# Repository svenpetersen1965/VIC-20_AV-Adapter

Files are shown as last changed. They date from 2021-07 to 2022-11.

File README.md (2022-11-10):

# VIC-20 A/V-Adapter
An Adapter for connecting the Commodore VIC-20 to video equipment with off the shelve A/V-cables.

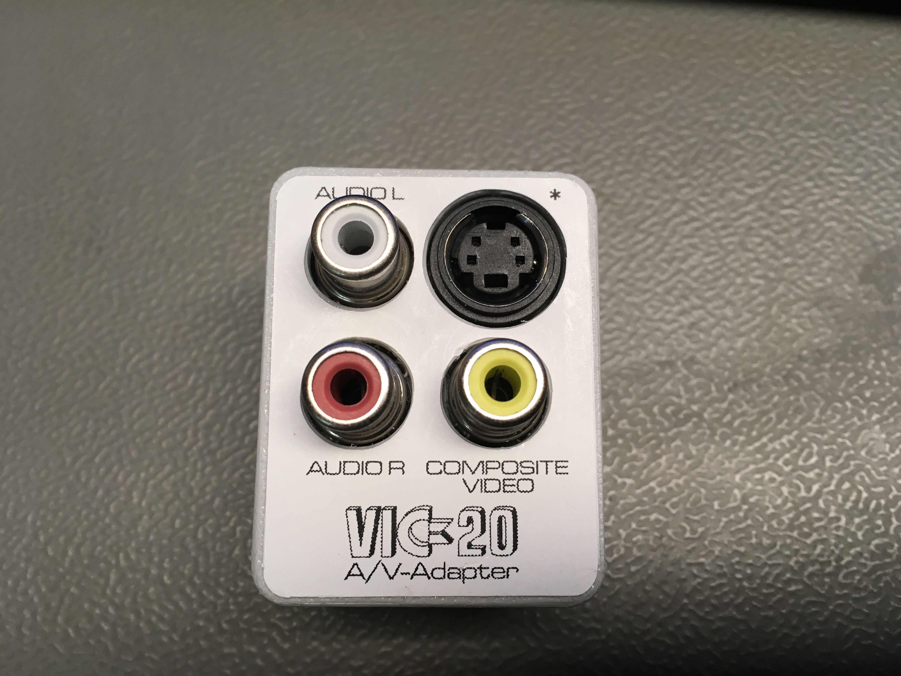
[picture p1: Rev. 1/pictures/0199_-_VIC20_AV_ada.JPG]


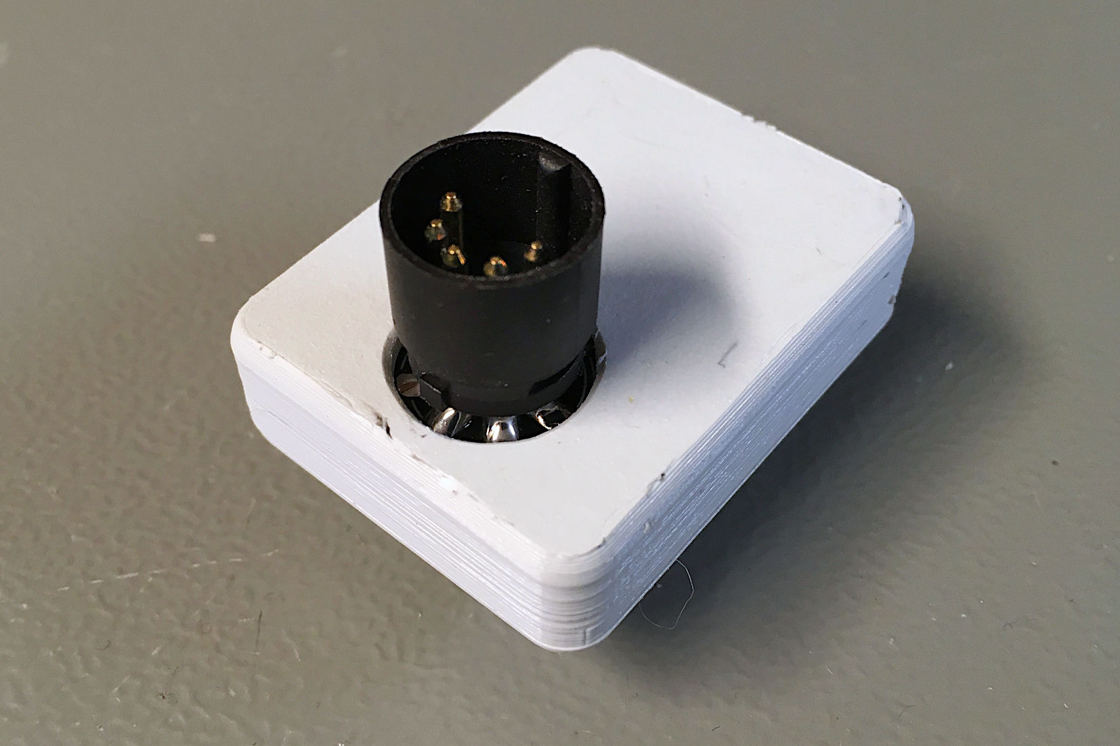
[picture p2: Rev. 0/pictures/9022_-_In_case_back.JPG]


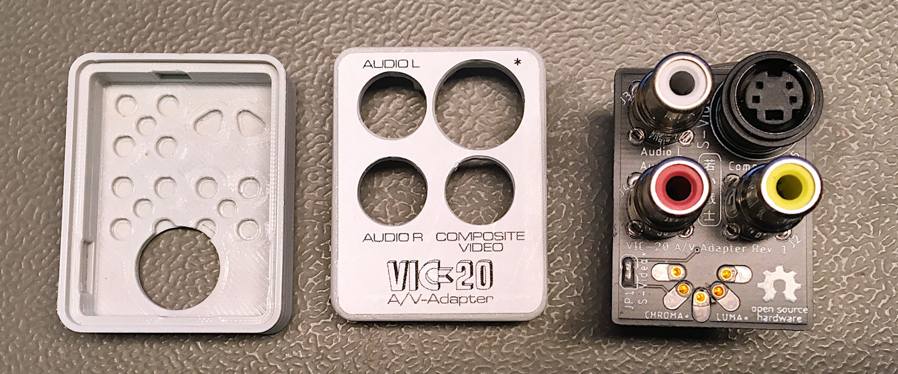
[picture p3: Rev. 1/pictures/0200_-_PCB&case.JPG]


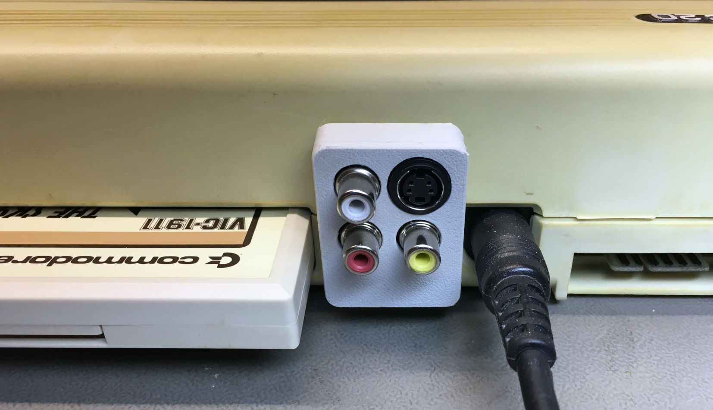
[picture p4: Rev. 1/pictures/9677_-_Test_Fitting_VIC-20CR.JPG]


A 3D printed case and a case label are provided in this repository.

The A/V-adapter was tested with
* the Commodore VIC-20
* the Commodore C16
* the Commodore C64
* the Atari 800XL

It is not suitable for the Commodore C128
# BOM Value
The BOM value of Rev. 1, without the 3D printed case and label is 9.50€ (01.11.2021, values obtained from Reichelt.de). The Lumberg connectors are more expensive from other suppliers.

# Rev. 2
The Lumberg BTOR1 RCA jacks were obsolete and replaced with CUI Inc. RCJ-02*. This also requires a different bottom shell of the 3D-printed case. There are Keystome RCA jacks, that fit the same footprint (they are more expensive). See the BOM Rev. 2

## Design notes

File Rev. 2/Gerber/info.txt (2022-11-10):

      
       Board: VIC-20_AV-Adaptor
       Rev.:  2
  
       Files:
       ======
  
       All Gerber files are generated in extended gerber format (RS274X)
       *.TOP        : Film top copper
       *.BOT        :  -"- bottom copper
       *.STC        :  -"- top soldermask 
       *.STS        :  -"- bottom soldermask
       *.PLC        :  -"- silk screen top
       *.PLS        :  -"- silk screen bottom
       *.DK         : Drills plated Through (Excellon)
       *.NDK        : Drills not plated Through (Excellon)
       *.OUT        : Board outline

       Board Size:
       ===========
       Length     :   39.0 mm
       Width      :   29.0 mm
       Thickness  :   1.6 mm
       Material   :   FR 4
       Copper     :   35 um
       Surface    :   HASL
       
       Remarks:
       ========
       Width >= 8mil
       Distance >= 6mil
       Drill >= 0.6mm

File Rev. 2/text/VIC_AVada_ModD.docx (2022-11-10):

-Commodore VIC-20 A/V-Adapter Rev. 2

Module Description

# Introduction

The VIC-20 A/V-Adapter serves as a breakout module for the 5-pin A/V jack, which allows using off the shelve cables of desired length and quality for connecting the VIC-20 to video/audio equipment.

The adapter is passive, it does not improve the video quality, but it helps to prevent video degradation. The S-Video jack works with VIC-20s, that are modified only. (S-Video mod like here: http://sleepingelephant.com/denial/wiki/index.php?title=S-Video_output or here: http://tech.guitarsite.de/vicky20_smod.html). The adapter does not generate S-Video!

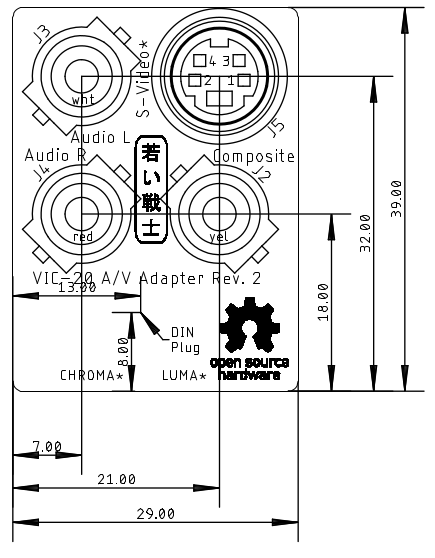
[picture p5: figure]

Figure 1: Dimensions of the PCB

The two audio jacks (Audio L and Audio R) are connected to the same signal, the (mono) Audio Out of the VIC-20.

A 3D printable case can be found in the project folder as well as a label for this case. The case for Rev. 0 and Rev. 1 is different from the case for Rev. 2.

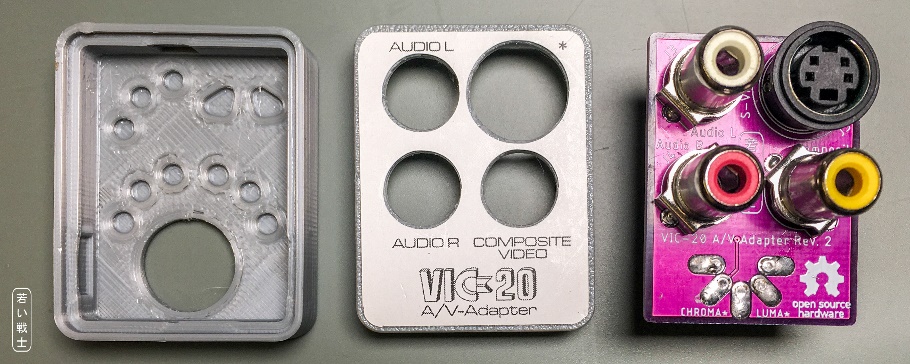
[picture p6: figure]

Figure 2: 3D printed case and assembled PCB

# Connectors

## A/V-Plug – J1

The A/V-Plug for the VIC-20 is the inner part of a Lumberg SV 50 DIN-Plug (180°).

Pin | Signal
1 | n.c.
2 | GND
3 | Audio Out (mono)
4 | Composite Video/LUMA*
5 | CHROMA*

* After S-Video mod.

## RCA-Jacks – J2, J3, J4

Connector | Signal
J2 | Composite Video
J3 | Audio Out L (mono!)
J4 | Audio Out R (mono!)

# The DIN-Plug

The DIN-Plug is an essential part of this development. It is the inner part of a Lumberg SV 50 connector, which is not cheap, but it is definitely worth the money, since the flange is taking the forces introduced by the weight of the adapter and the cables. This way, the set-up is not hanging from the contacts, which might even damage those. Do not use a cheap connector without a flange, here.

# Assembly

First, the DIN connector has to be soldered. The pins should be aligned flush to the top side of the PCB. This can be accomplished by putting the PCB top down on a heat resistant, flat surface. Then solder one pin from the top (the solder pads are shaped in a way, that allows doing so), check, if it is really flush and the connector is perpendicular to the board, then solder the remaining pins.

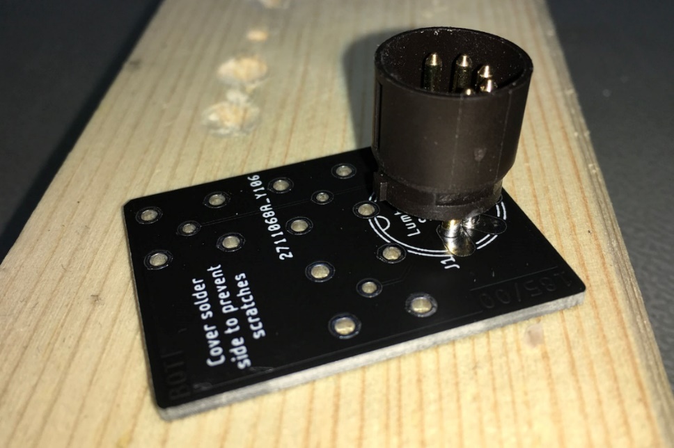
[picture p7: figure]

Figure 3: Aligning the DIN-Connector (PCB Rev. 0)

Now, place and solder the mini-DIN and finally the RCA jacks. They should be well aligned, too. The ground pins might require more energy to be soldered, so the use of a thick solder tip is recommended and may be even a higher temperature (450°C). After soldering, the pins should be trimmed (shorter than 1.5mm), so they fit into the 3D-Printed case. If you do not use a case, cover the pins with something like duct tape or small drops of hot glue to prevent scratching the case of your VIC-20.

# Compatibility

The adapter also fits the C64 (in case S-Video is not required), especially the first C64 model with the 5-pin A/V-jack (this does not have the S-Video outputs). The same is for the C16. The VIC-20 A/V-Adapter does not work for the C128, since it blocks the serial bus. The adapter was also successfully tested with an Atari 800XL (composite).

# Annotation

The said S-Video mod exposes the CHROMA pin of the VIC chip almost directly to the connector. This might get critical, if the VIC-20or any of the video devices is switched on/connected to a PSU. I would definitely recommend a careful way of connecting the cables and devices.

# Revision History

## Rev. 0

- Fully functional prototype

## Rev. 0 → Rev. 1

- S-Video jack for modified VIC-20 added.

## Rev. 1 → Rev. 2

- Replaced the obsolescent Lumberg BTOR1 RCA-jacks with CUI Inc. RCJ-02x type. There are alternative Keystone parts, that fit the same footprint (see BOM v2).
- A new 3D-pinted case is required (bottom shell)

VIC_AVada_ModD.docx 10.11.2022 16:17 Drafted by Sven Petersen Page 2 of 2 Doc.-No.: 185-6-01-02

VIC_AVada_ModD.docx 10.11.2022 16:17 Drafted by Sven Petersen Page 1 of 1 Doc.-No.: 000-6-00-00

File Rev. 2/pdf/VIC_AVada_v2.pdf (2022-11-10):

# Project Documentation

## Commodore VIC-20 A/V-Adapter

## Project number: 185

## Revision: 2

## Date: 10.11.2022

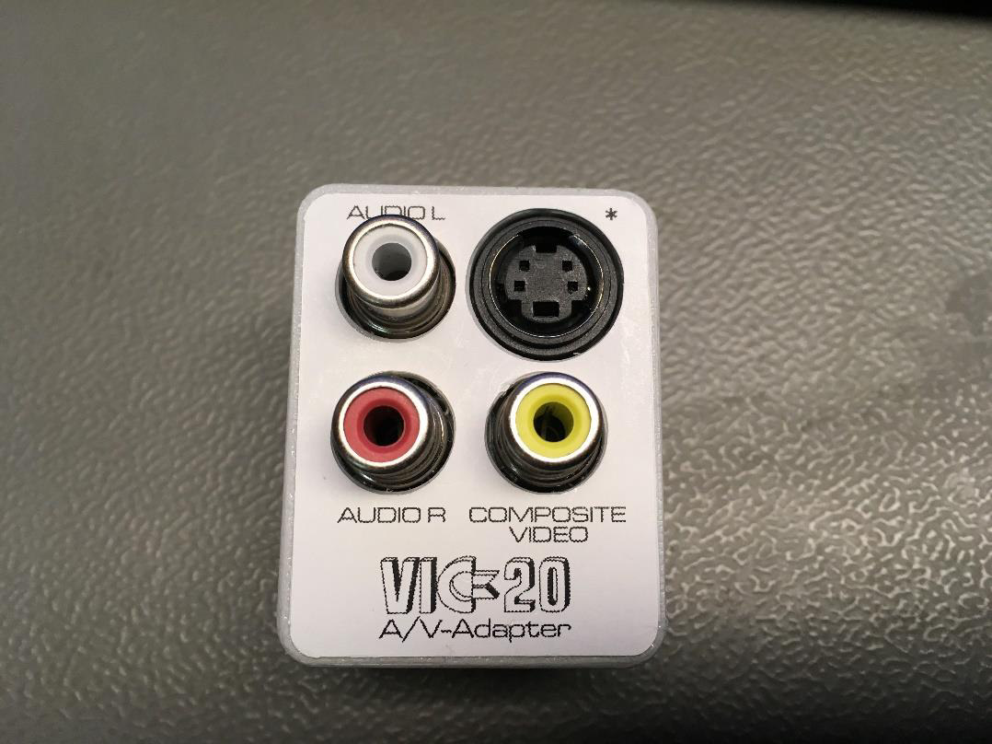
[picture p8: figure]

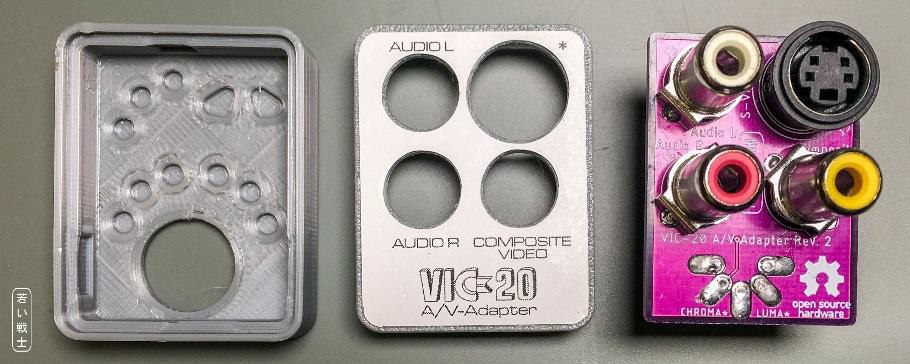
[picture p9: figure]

VIC_AVada_ModD.docx | | 10.11.2022 16:17
Drafted by Sven Petersen | Page 1 of 3 | Doc.-No.: 185-6-01-02

### -Commodore VIC-20 A/V-Adapter Rev. 2

### Module Description

## Introduction

The VIC-20 A/V-Adapter serves as a breakout module for the 5-pin A/V jack, which allows using off the shelve cables of desired length and quality for connecting the VIC-20 to video/audio equipment.

The adapter is passive, it does not improve the video quality, but it helps to prevent video degradation. The S-Video jack works with VIC-20s, that are modified only. (S-Video mod like
here: | http://sleepingelephant.com/denial/wiki/index.php?title=S-Video_output | or | here:
http://tech.guitarsite.de/vicky20_smod.html). The adapter does not generate S-Video!

Figure 1: Dimensions of the PCB

The two audio jacks (Audio L and Audio R) are connected to the same signal, the (mono) Audio Out of the VIC-20.

A 3D printable case can be found in the project folder as well as a label for this case. The case for Rev. 0 and Rev. 1 is different from the case for Rev. 2.

Figure 2: 3D printed case and assembled PCB

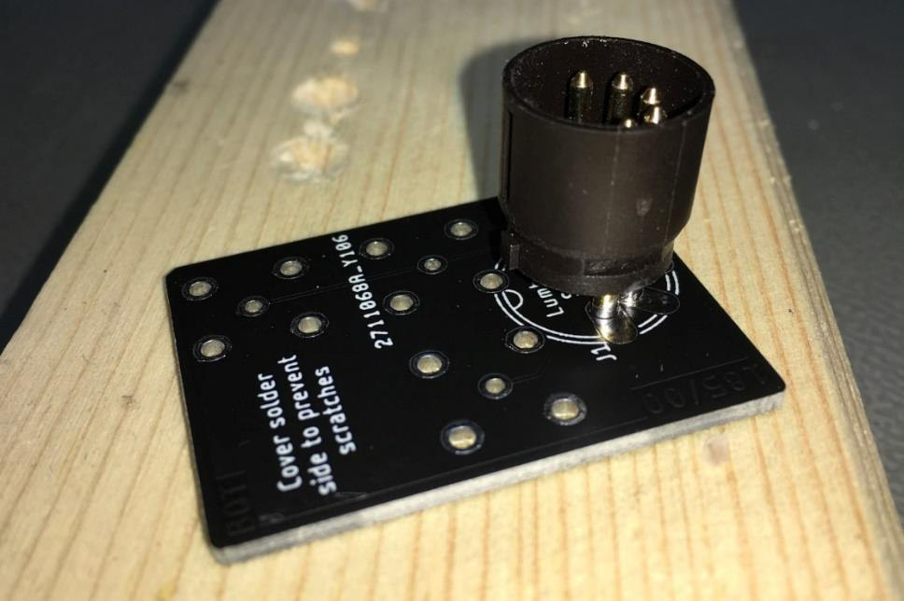
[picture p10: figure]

VIC_AVada_ModD.docx | | 10.11.2022 16:17
Drafted by Sven Petersen | Page 2 of 3 | Doc.-No.: 185-6-01-02

## Connectors

### A/V-Plug – J1

The A/V-Plug for the VIC-20 is the inner part of a Lumberg SV 50 DIN-Plug (180°).

Pin Signal
1 n.c.
2 GND
3 Audio Out (mono)
4 Composite Video/LUMA*
5 CHROMA*

* After S-Video mod.

### RCA-Jacks – J2, J3, J4

Connector Signal
J2 | Composite Video
J3 | Audio Out L (mono!)
J4 | Audio Out R (mono!)

## The DIN-Plug

The DIN-Plug is an essential part of this development. It is the inner part of a Lumberg SV 50 connector, which is not cheap, but it is definitely worth the money, since the flange is taking the forces introduced by the weight of the adapter and the cables. This way, the set-up is not hanging from the contacts, which might even damage those. Do not use a cheap connector without a flange, here.

## Assembly

First, the DIN connector has to be soldered. The pins should be aligned flush to the top side of the PCB. This can be accomplished by putting the PCB top down on a heat resistant, flat surface. Then solder one pin from the top (the solder pads are shaped in a way, that allows doing so), check, if it is really flush and the connector is perpendicular to the board, then solder the remaining pins.

Figure 3: Aligning the DIN-Connector (PCB Rev. 0)

VIC_AVada_ModD.docx | | 10.11.2022 16:17
Drafted by Sven Petersen | Page 3 of 3 | Doc.-No.: 185-6-01-02

Now, place and solder the mini-DIN and finally the RCA jacks. They should be well aligned, too. The ground pins might require more energy to be soldered, so the use of a thick solder tip is recommended and may be even a higher temperature (450°C). After soldering, the pins should be trimmed (shorter than 1.5mm), so they fit into the 3D-Printed case. If you do not use a case, cover the pins with something like duct tape or small drops of hot glue to prevent scratching the case of your VIC-20.

## Compatibility

The adapter also fits the C64 (in case S-Video is not required), especially the first C64 model with the 5-pin A/V-jack (this does not have the S-Video outputs). The same is for the C16. The VIC-20 A/V-Adapter does not work for the C128, since it blocks the serial bus. The adapter was also successfully tested with an Atari 800XL (composite).

## Annotation

The said S-Video mod exposes the CHROMA pin of the VIC chip almost directly to the connector. This might get critical, if the VIC-20or any of the video devices is switched on/connected to a PSU. I would definitely recommend a careful way of connecting the cables and devices.

## Revision History

### Rev. 0

- Fully functional prototype

### Rev. 0 → Rev. 1

- S-Video jack for modified VIC-20 added.

### Rev. 1 → Rev. 2

- Replaced the obsolescent Lumberg BTOR1 RCA-jacks with CUI Inc. RCJ-02x type. There are alternative Keystone parts, that fit the same footprint (see BOM v2).
- A new 3D-pinted case is required (bottom shell)

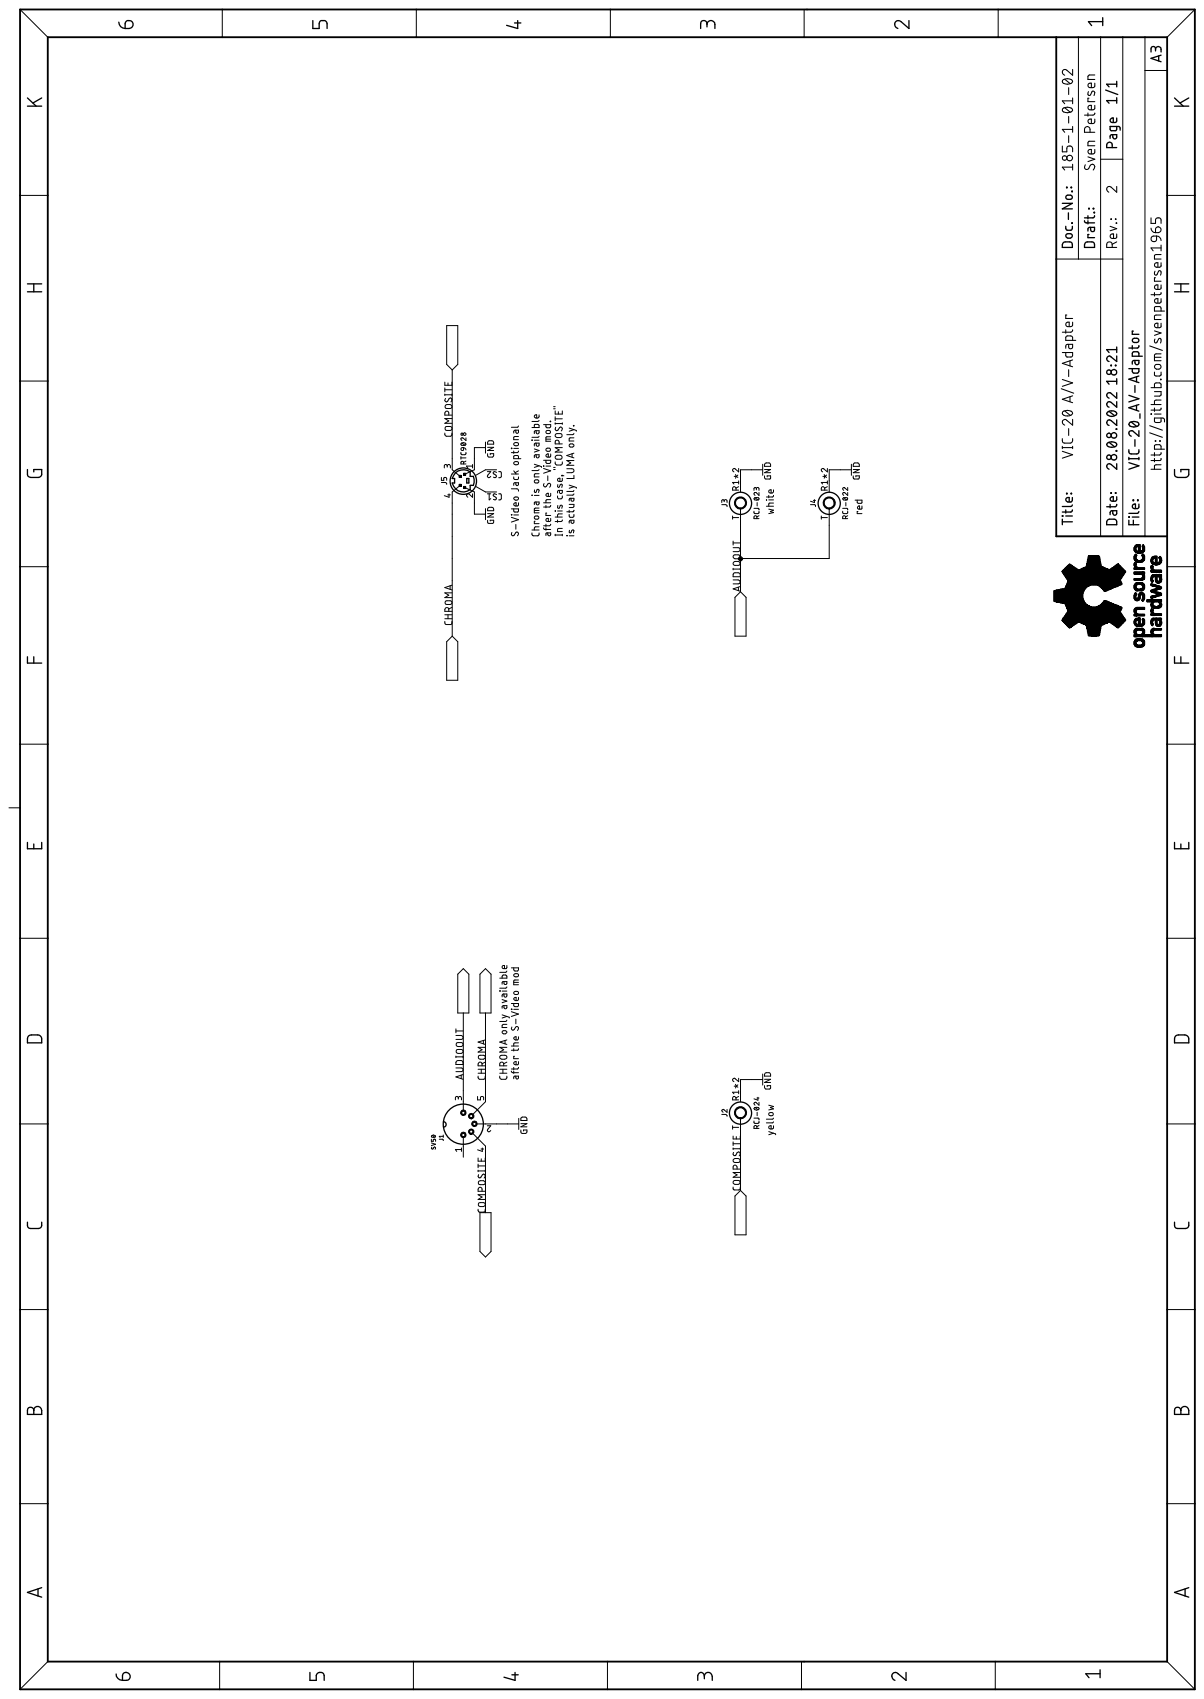
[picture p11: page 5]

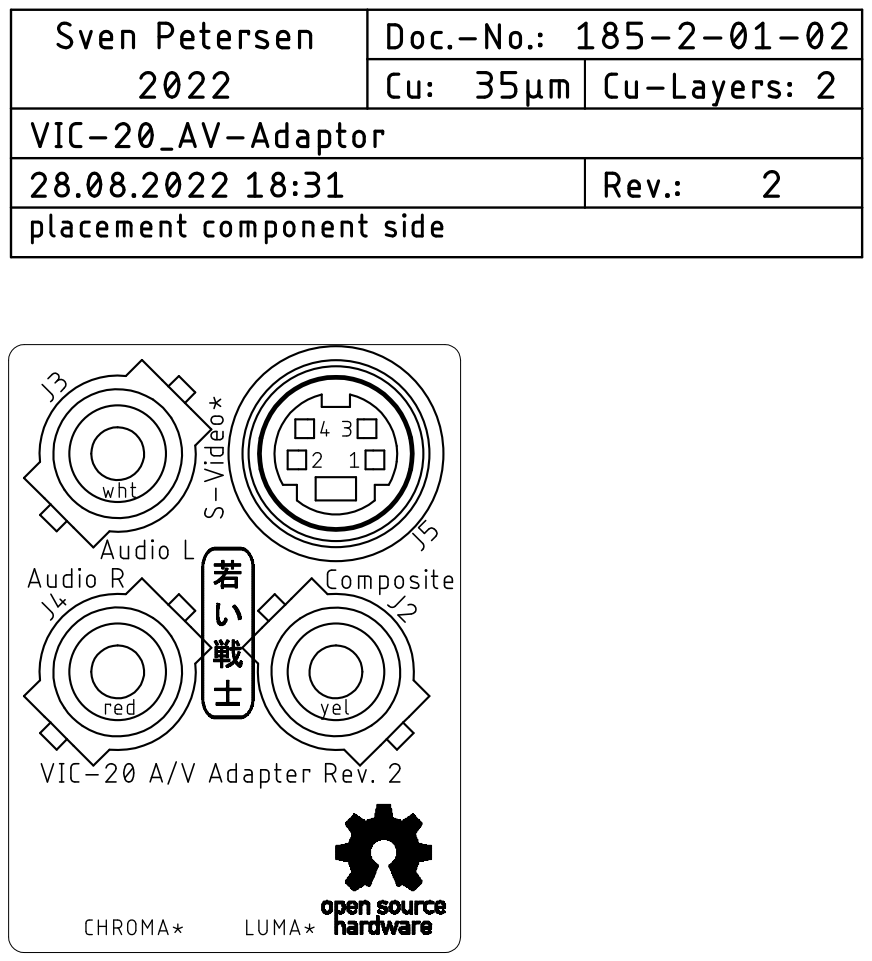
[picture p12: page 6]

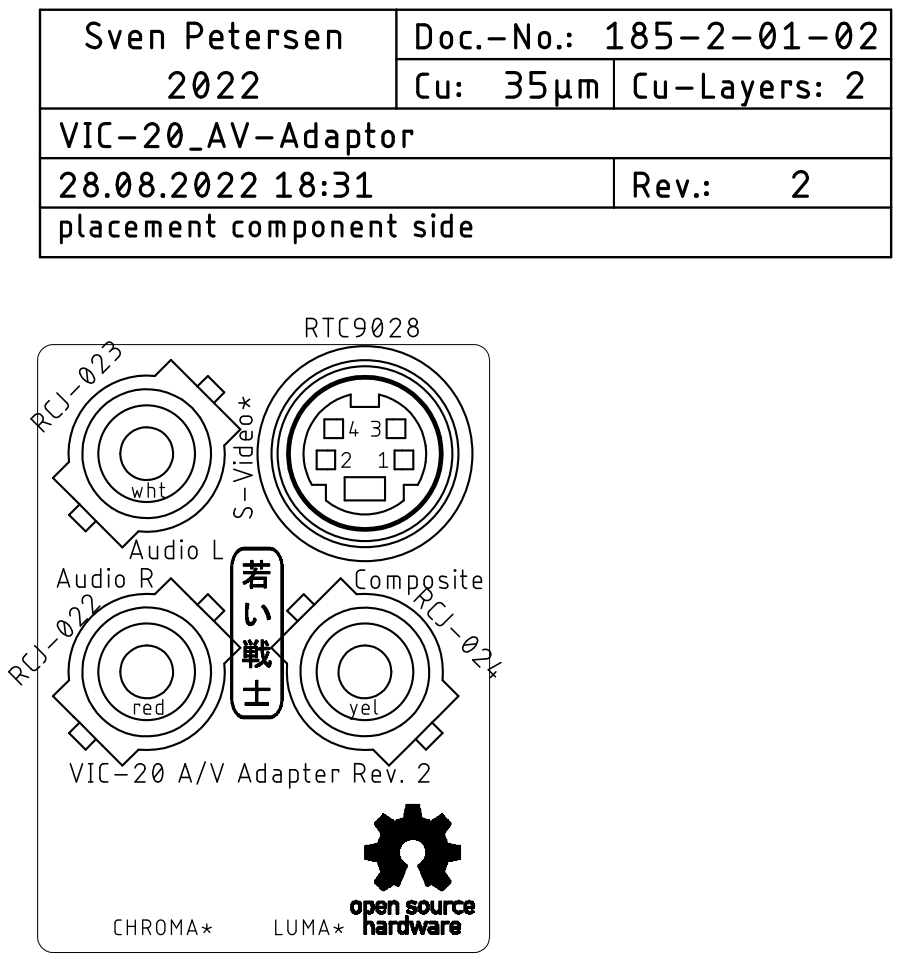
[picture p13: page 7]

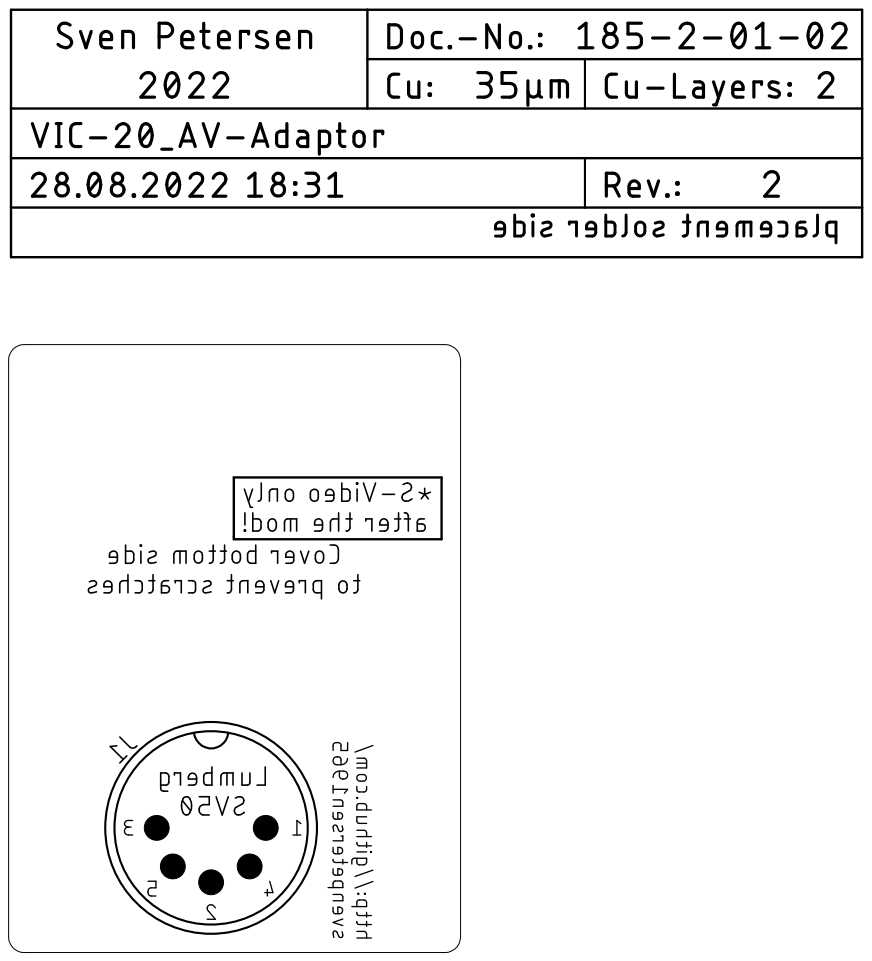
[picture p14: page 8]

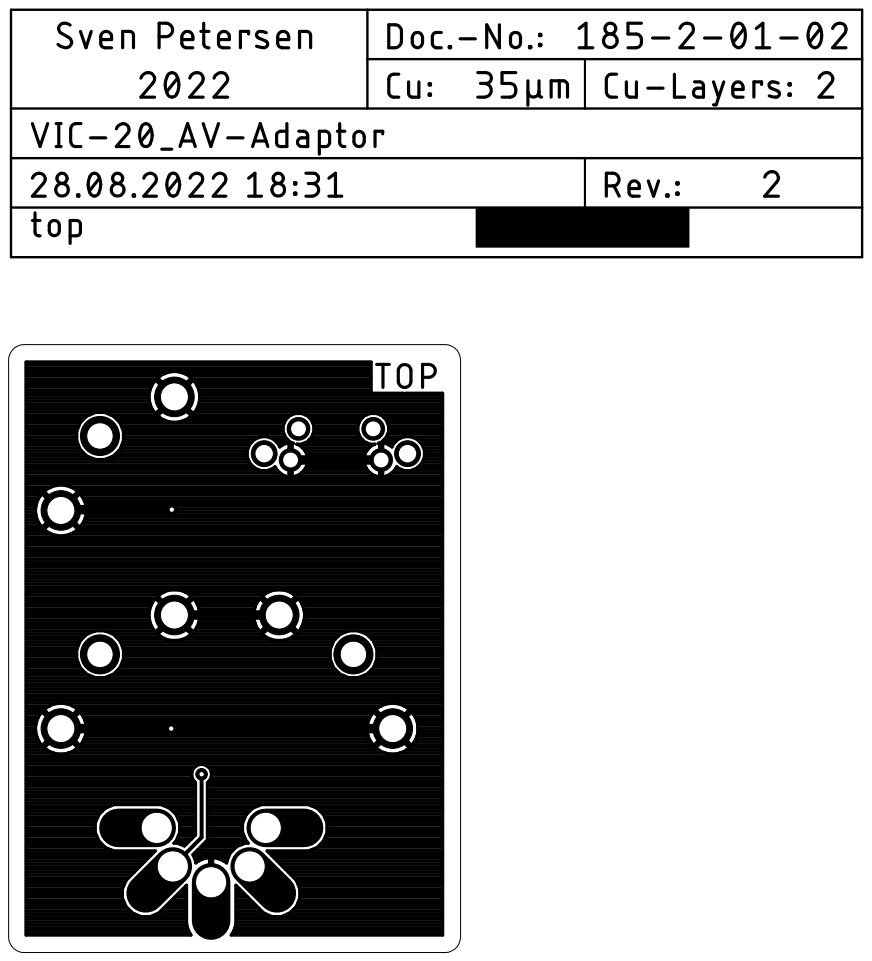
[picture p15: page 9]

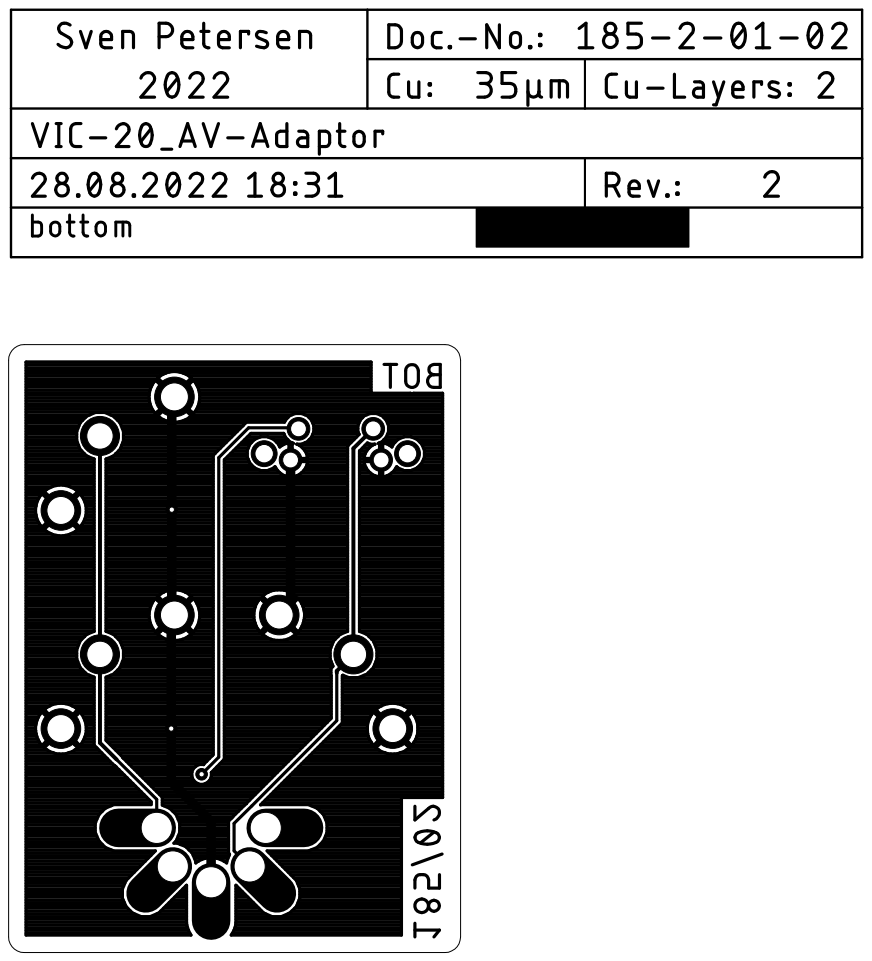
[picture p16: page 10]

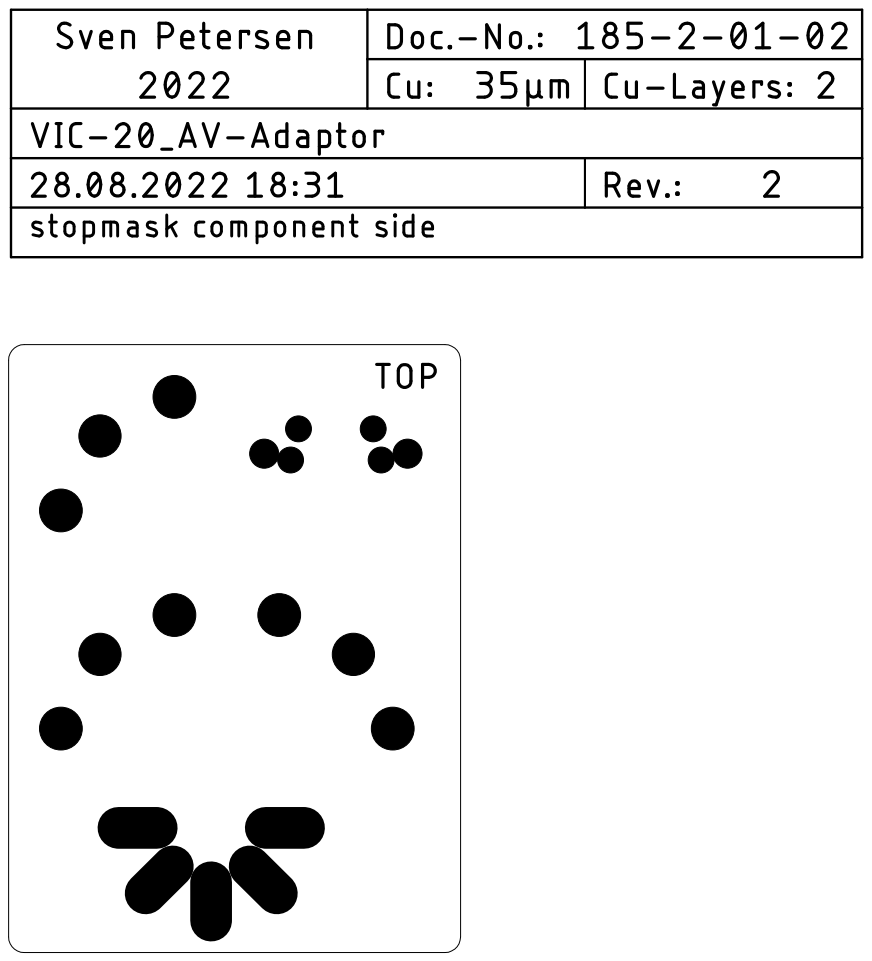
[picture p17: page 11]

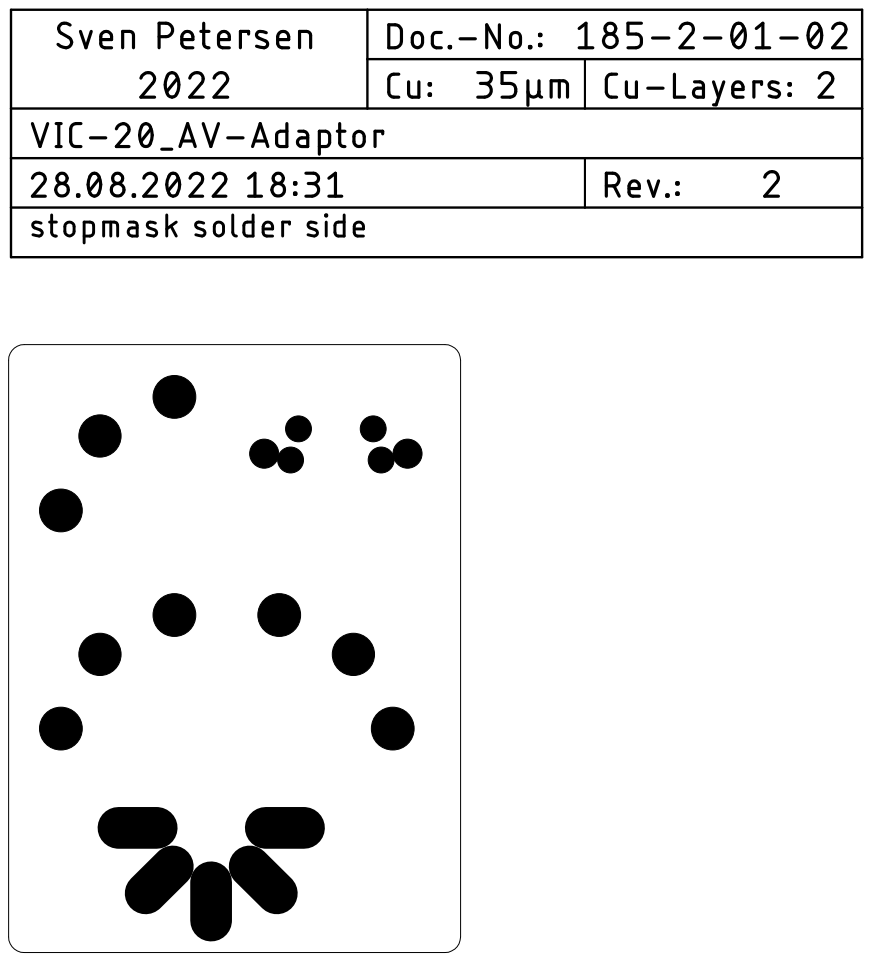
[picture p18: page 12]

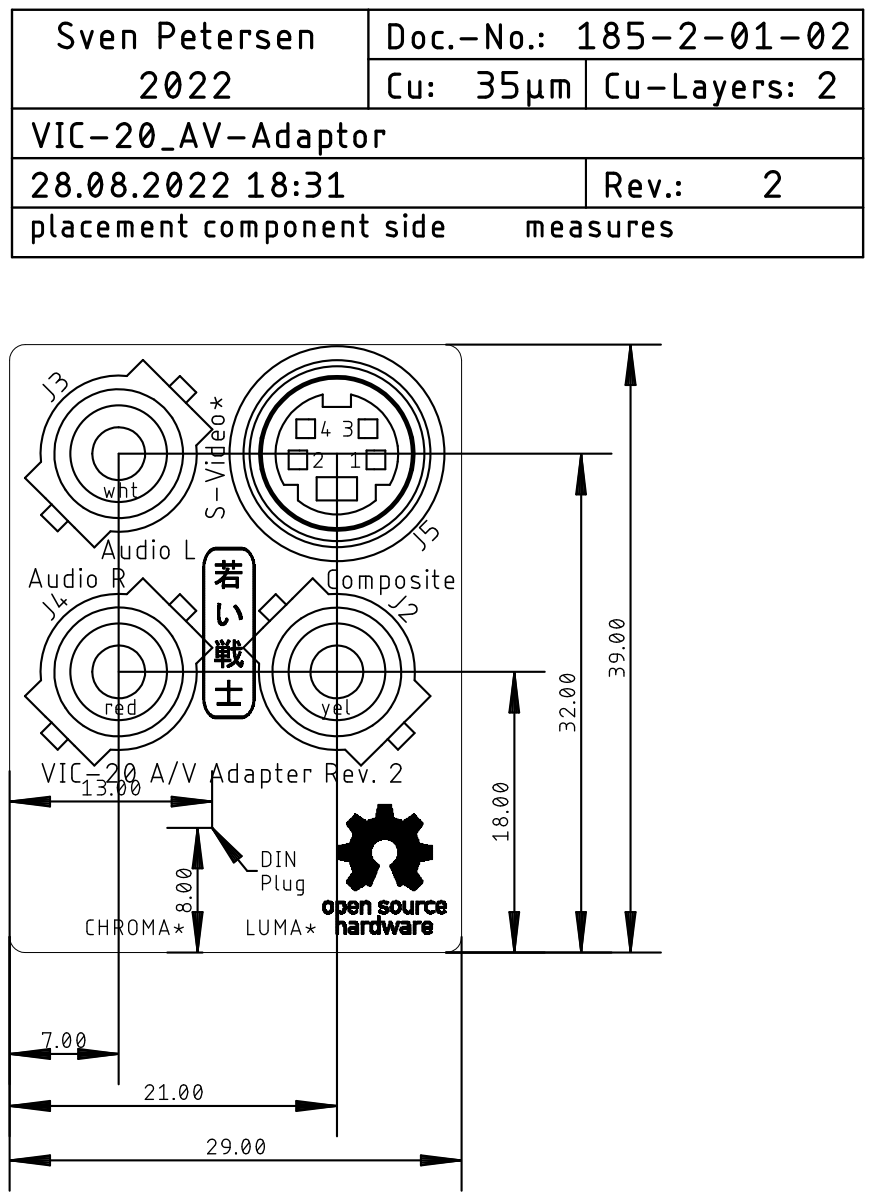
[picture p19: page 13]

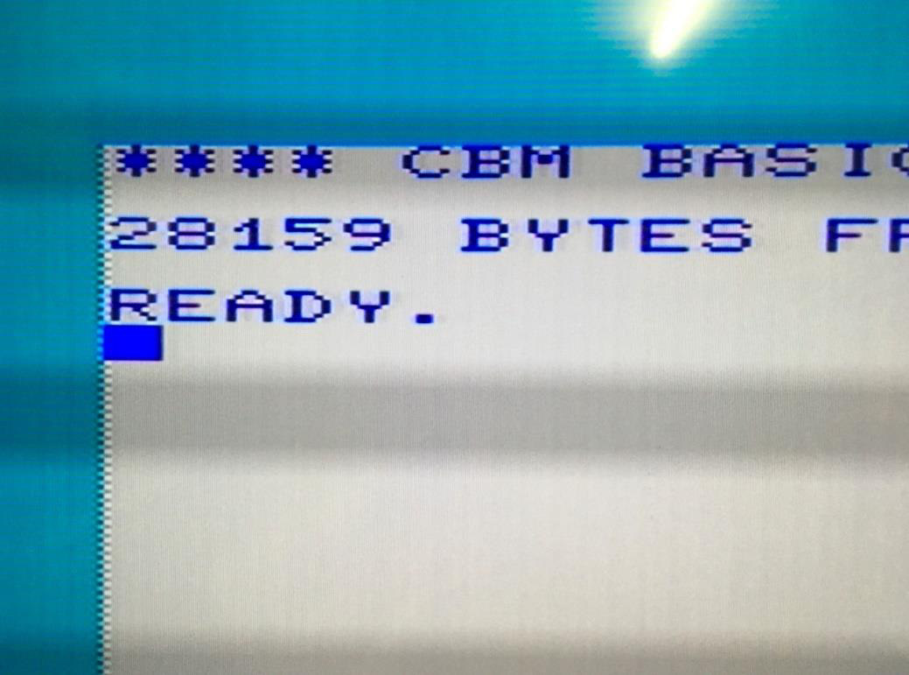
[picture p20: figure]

VIC_AVada_Test.docx | | 10.11.2022 16:18
Drafted by Sven Petersen | Page 1 of 7 | Doc.-No.: 185-6-02-02

### Commodore VIC-20 A/V-Adapter Rev. 2

### Test

## Test Setup

The tests were executed with a VIC-20 A/V-Adapter Rev. 1 and Rev. 2. These computers were used for testing:

1. A VickyTwenty (clone of the VIC-20CR) in a plexilaser.de case
2. A two-prong VIC-20 (ASSY No. 324003)
3. A VIC-20CR (ASSY No. ASSY250403)
4. C64 ASSY No. 250469

The VickyTwenty has the S-Video modification (sleepingelephant.com (http://sleepingelephant.com/denial/wiki/index.php?title=S-Video_output) or tech.guitarsite.de, (http://tech.guitarsite.de/vicky20_smod.html) respectively).

The retroTINK 2x (used with the HDMI capture device), the Framemeister (used with the TV) and a Samsung smart TV served as video equipment. A 1.5m RCA A/V cable connected the computer to the video equipment.

## Functional Test

The A/V adapter was connected to the computers and the video was displayed properly, the audio could be heard.

Figure 1: Boot screen of the VIC-20 CR (Hyper Expander RAM expansion installed)

The video quality was as good as it can get with the unmodified VIC-20. The video quality of ASSY No. 324003 is best, next is the Vicky Twenty.

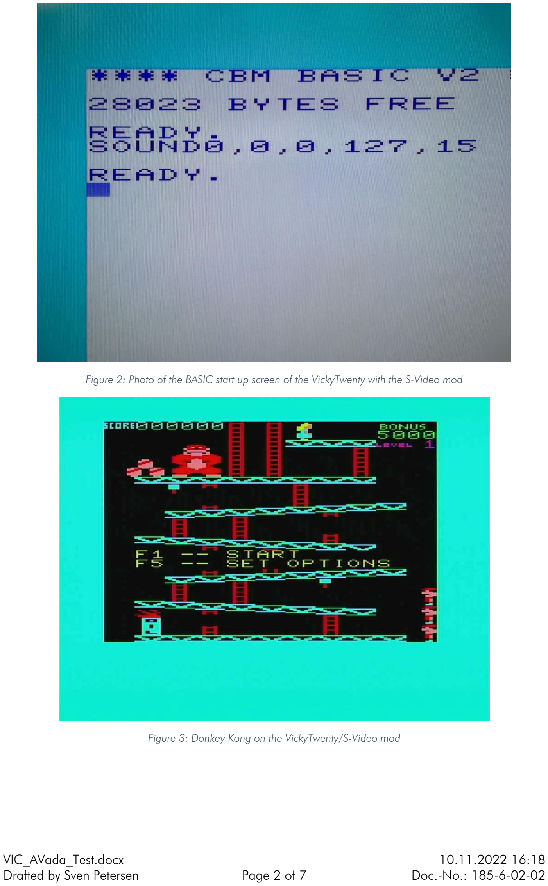
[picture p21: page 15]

VIC_AVada_Test.docx | | 10.11.2022 16:18
Drafted by Sven Petersen | Page 2 of 7 | Doc.-No.: 185-6-02-02

Figure 2: Photo of the BASIC start up screen of the VickyTwenty with the S-Video mod

Figure 3: Donkey Kong on the VickyTwenty/S-Video mod

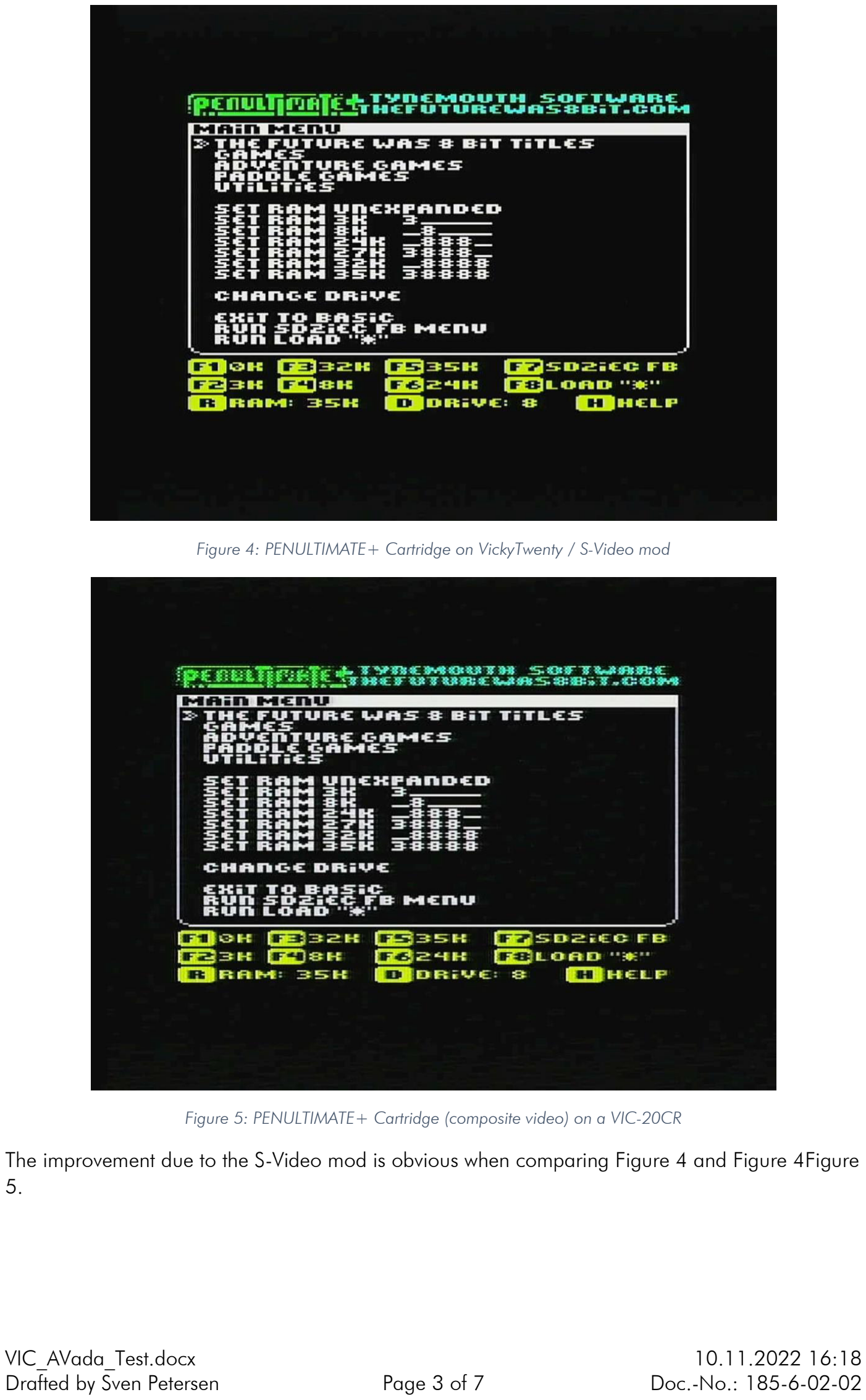
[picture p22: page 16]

VIC_AVada_Test.docx | | 10.11.2022 16:18
Drafted by Sven Petersen | Page 3 of 7 | Doc.-No.: 185-6-02-02

Figure 4: PENULTIMATE+ Cartridge on VickyTwenty / S-Video mod

Figure 5: PENULTIMATE+ Cartridge (composite video) on a VIC-20CR

The improvement due to the S-Video mod is obvious when comparing Figure 4 and Figure 4Figure 5.

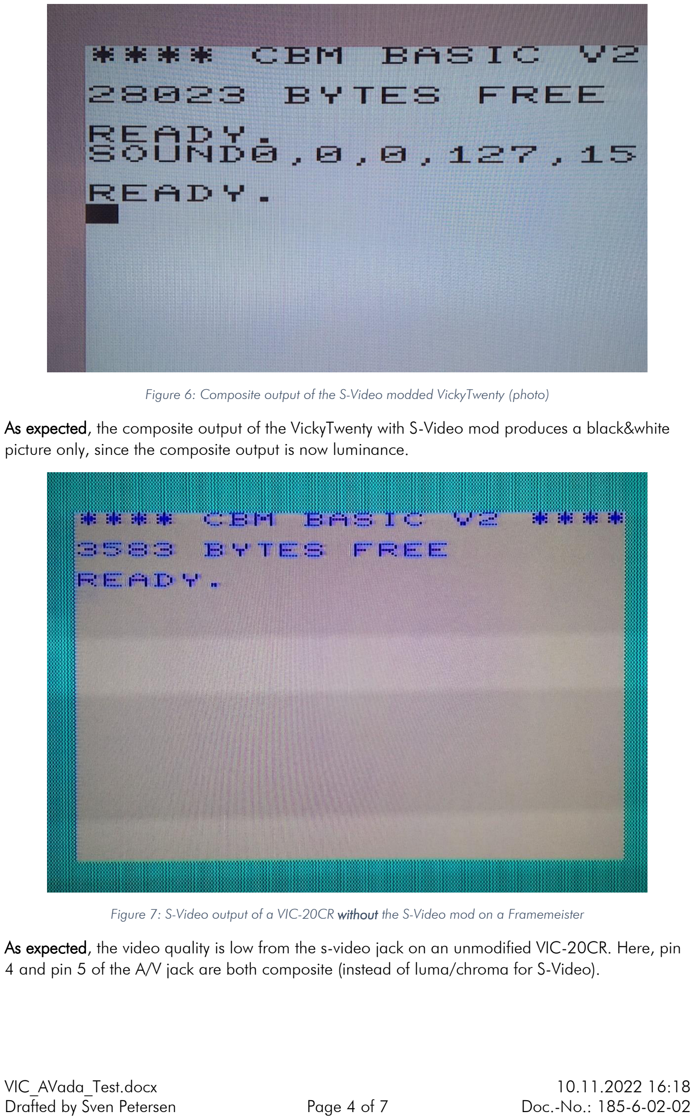
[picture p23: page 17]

VIC_AVada_Test.docx | | 10.11.2022 16:18
Drafted by Sven Petersen | Page 4 of 7 | Doc.-No.: 185-6-02-02

Figure 6: Composite output of the S-Video modded VickyTwenty (photo)

As expected, the composite output of the VickyTwenty with S-Video mod produces a black&white picture only, since the composite output is now luminance.

Figure 7: S-Video output of a VIC-20CR without the S-Video mod on a Framemeister

As expected, the video quality is low from the s-video jack on an unmodified VIC-20CR. Here, pin 4 and pin 5 of the A/V jack are both composite (instead of luma/chroma for S-Video).

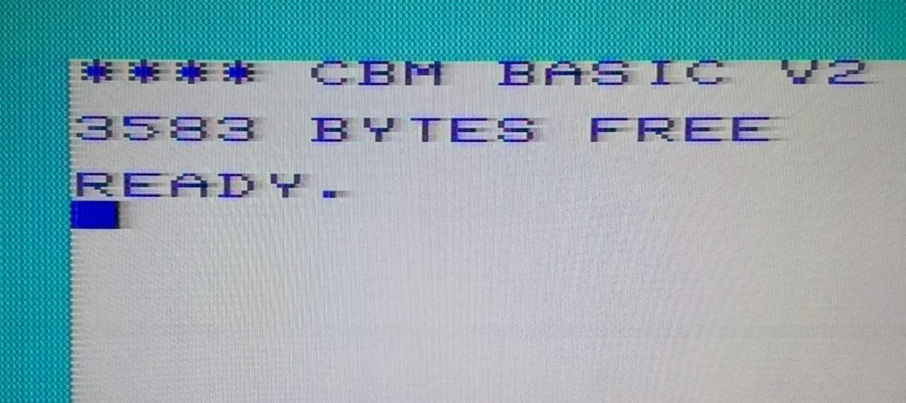
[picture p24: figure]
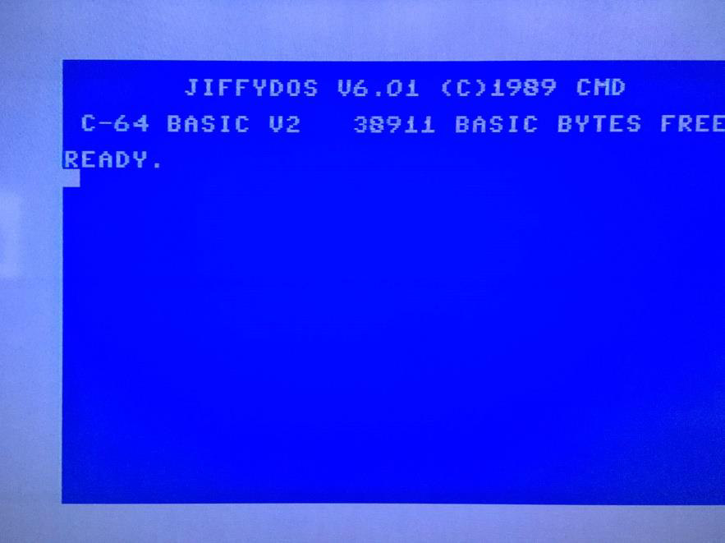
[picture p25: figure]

VIC_AVada_Test.docx | | 10.11.2022 16:18
Drafted by Sven Petersen | Page 5 of 7 | Doc.-No.: 185-6-02-02

Figure 8: S-Video output of the unmodified VIC-20 (2 prong)

As expected, the output is degraded. The 2-prong VIC-20 has a different video circuitry as the VIC-20CR. Pin 4 and pin 5 are not tied together, but pin 4 is a composite signal (Pin 5) after an L/C-
low pass filter. Thus, the different output “quality” of incorrectly connected VIC-20s.

Figure 9: Photo of the C64 boot screen (composite Video)

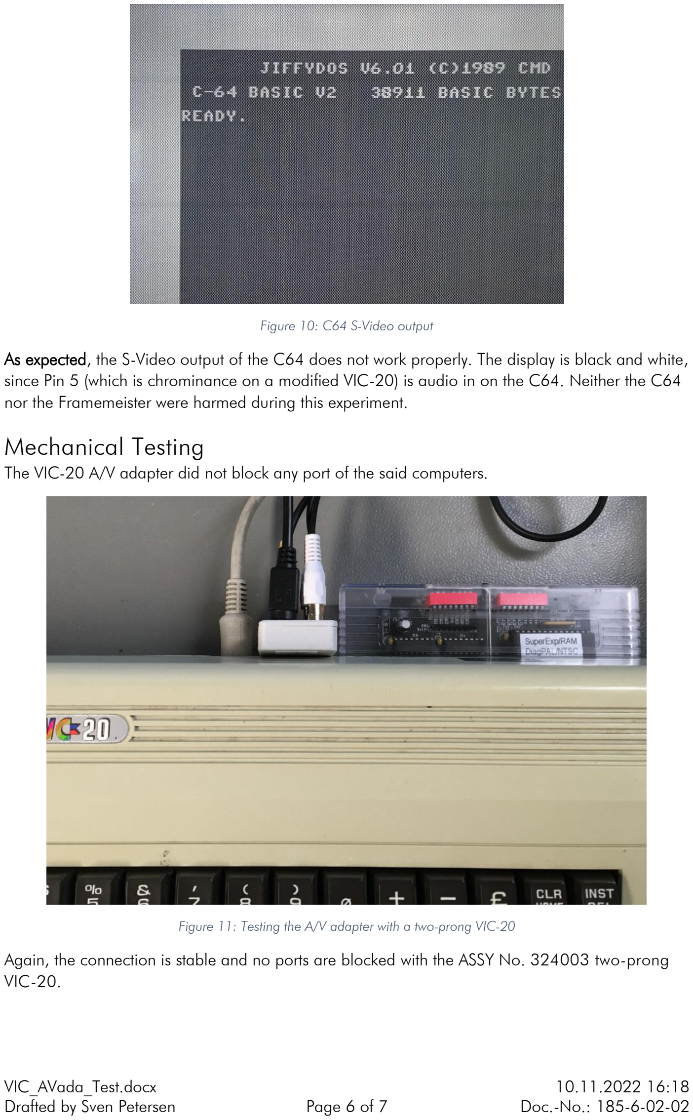
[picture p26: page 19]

VIC_AVada_Test.docx | | 10.11.2022 16:18
Drafted by Sven Petersen | Page 6 of 7 | Doc.-No.: 185-6-02-02

Figure 10: C64 S-Video output

As expected, the S-Video output of the C64 does not work properly. The display is black and white, since Pin 5 (which is chrominance on a modified VIC-20) is audio in on the C64. Neither the C64 nor the Framemeister were harmed during this experiment.

## Mechanical Testing

The VIC-20 A/V adapter did not block any port of the said computers.

Figure 11: Testing the A/V adapter with a two-prong VIC-20

Again, the connection is stable and no ports are blocked with the ASSY No. 324003 two-prong VIC-20.

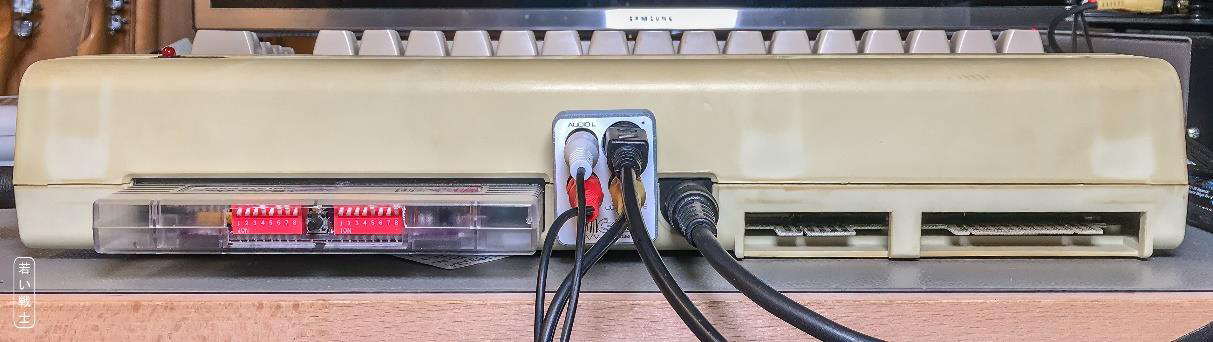
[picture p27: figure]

VIC_AVada_Test.docx | | 10.11.2022 16:18
Drafted by Sven Petersen | Page 7 of 7 | Doc.-No.: 185-6-02-02

Figure 12: Fitting of the A/V-Adapter with a VIC-20CR

## Conclusion

The VIC-20 A/V-Adapter works well with different equipment. The video quality depends very much on the used video equipment. The video adapter will not improve the picture of the computers, since it is passive only, but since it allows to use good, off the shelve cables, it is superior to most handmade custom cables.

Connecting S-Video to not modified VIC-20s does not harm the video equipment or the computer, but the quality is degraded. The same applies to the C64, which has its dedicated S-Video pins, that are not connected to the S-Video jack of the VIC-20 A/V-Adapter. The composite out of the C64 is displayed properly through the VIC-20 A/V-Adapter.

The VIC-20 A/V-Adaptor Rev. 2 is fully functional.

Pos. Qty Value Footprint Ref.-No. Comment

1 1 185-2-01-02 2 Layer PCB Rev. 2 2 layer, Cu 35µ, HASL, 39.0mm x 29.0mm, 1.6mm FR4
2 1 RCJ-022 RCJ-02X J4 CUI Inc., RCA jack, vertical, red. Mouser: 490-RCJ-022,
Digikey: CP-1407-ND. Alternative part: Keystone 577

3 1 RCJ-023 RCJ-02X J3 CUI Inc., RCA jack, vertical, white. Mouser: 490-RCJ-023,
Digikey: CP-1408-ND. Alternative part: Keystone 584

4 1 RCJ-024 RCJ-02X J2 CUI Inc., RCA jack, vertical, yellow. Mouser: 490-RCJ-024,

Digikey: CP-1409-ND. Alternative part: Keystone 586

5 1 SV50 SV50_INNER J1 Inner part of Lumberg SV 50 (SV 50-8), e.G. Reichelt: LUM
SV 50, Newark: 82AH3339 , Farnell: 3549652, TME.eu:

SV50, alliedelec.com: 70151556

6 1 solder bridge JP1 structure on PCB, close for proper operation

7 1 RTC9028 MINIDIN4_V J5 Mini-DIN, 4p, vertical. Not required for 5-pin and VIC-20.

E.g. AliExpress:

### 8 RTConnector: RTC9028

### 9 ebay.de

### Rev. 1.0 → Rev. 2.0

Pos. 1 pcb revision

Pos. 2 new RCA jack

Pos. 3 new RCA jack

Pos. 4 new RCA jack

## VIC-20 A/V-Adaptor Rev. 2

## Bill of Material Rev. 2.0

VIC20_AV_Adapt_BOM_v2_0.xlsx

Drafted by Sven Petersen Page 1 of 1

10.11.2022 16:28
Doc.No.: 185-5-01-02.0

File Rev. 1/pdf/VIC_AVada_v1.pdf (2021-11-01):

# Project Documentation

## Commodore VIC-20 A/V-Adapter

## Project number: 185

## Revision: 1

## Date: 04.09.2021

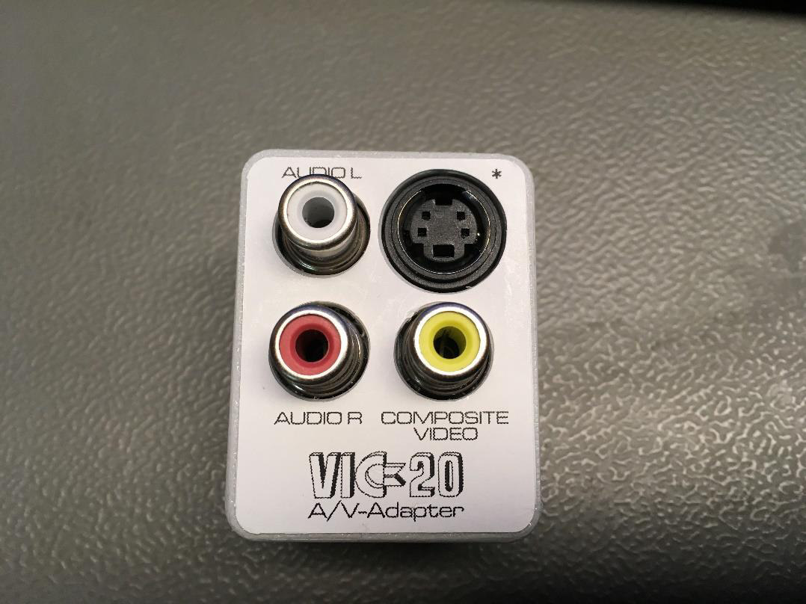
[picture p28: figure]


VIC_AVada_ModD.docx | | 01.11.2021 13:15
Drafted by Sven Petersen | Page 1 of 3 | Doc.-No.: 185-6-01-01

### Commodore VIC-20 A/V-Adapter Rev. 1

### Module Description

## Introduction

The VIC-20 A/V-Adapter serves as a breakout module for the 5-pin A/V jack, which allows using off the shelve cables of desired length and quality for connecting the VIC-20 to video/audio equipment.

The adapter is passive, it does not improve the video quality, but it helps to prevent video degradation. The S-Video jack works with VIC-20s, that are modified only. (S-Video mod like
here: | http://sleepingelephant.com/denial/wiki/index.php?title=S-Video_output | or | here:
http://tech.guitarsite.de/vicky20_smod.html). The adapter does not generate S-Video!

Figure 1: Dimensions of the PCB

The two audio jacks (Audio L and Audio R) are connected to the same signal, the (mono) Audio Out of the VIC-20.

A 3D printable case can be found in the project folder as well as a label for this case. The case for Rev. 0 is different from the case for Rev. 1.

Figure 2: 3D printed case and assembled PCB

VIC_AVada_ModD.docx | | 01.11.2021 13:15
Drafted by Sven Petersen | Page 2 of 3 | Doc.-No.: 185-6-01-01

## Connectors

### A/V-Plug – J1

The A/V-Plug for the VIC-20 is the inner part of a Lumberg SV 50 DIN-Plug (180°).

Pin Signal
1 n.c.
2 GND
3 Audio Out (mono)
4 Composite Video/LUMA*
5 CHROMA*

* After S-Video mod.

### RCA-Jacks – J2, J3, J4

Connector Signal
J2 | Composite Video
J3 | Audio Out L (mono!)
J4 | Audio Out R (mono!)

## The DIN-Plug

The DIN-Plug is an essential part of this development. It is the inner part of a Lumberg SV 50 connector, which is not cheap, but it is definitely worth the money, since the flange is taking the forces introduced by the weight of the adapter and the cables. This way, the set-up is not hanging from the contacts, which might even damage those. Do not use a cheap connector without a flange, here.


VIC_AVada_ModD.docx | | 01.11.2021 13:15
Drafted by Sven Petersen | Page 3 of 3 | Doc.-No.: 185-6-01-01

## Assembly

First, the DIN connector has to be soldered. The pins should be aligned flush to the top side of the PCB. This can be accomplished by putting the PCB top down on a heat resistant, flat surface. Then solder one pin from the top (the solder pads are shaped in a way, that allows doing so), check, if it is really flush and the connector is perpendicular to the board, then solder the remaining pins.

Figure 3: Aligning the DIN-Connector

Now, place and solder the RCA jacks. They should be well aligned, too. The ground pins might require more energy to be soldered, so the use of a thick solder tip is recommended and may be even a higher temperature (450°C). After soldering, the pins should be trimmed (shorter than 1.5mm), so they fit into the 3D-Printed case. If you do not use a case, cover the pins with something like duct tape or small drops of hot glue to prevent scratching the case of your VIC-20.

DO NOT FORGET to close JP1. This had experimental character and it needs to be closed for chroma reaching the S-Video jack.

## Compatibility

The adapter also fits the C64 (in case S-Video is not required), especially the first C64 model with the 5-pin A/V-jack (this does not have the S-Video outputs). The same is for the C16. The A/V-Adapter does not work for the C128, since it blocks the serial bus. The adapter was successfully tested with an Atari 800XL.

## Revision History

### Rev. 0

- Fully functional prototype

### Rev. 0 → Rev. 1

- S-Video jack for modified VIC-20 added.











VIC_AVada_Test.docx | | 01.11.2021 12:37
Drafted by Sven Petersen | Page 1 of 8 | Doc.-No.: 185-6-02-01

### Commodore VIC-20 A/V-Adapter Rev. 1

### Test

## Test Setup

The tests were executed with a VIC-20 A/V-Adapter Rev. 1. These computers were used for testing:

1. A VickyTwenty (clone of the VIC-20CR) in a plexilaser.de case
2. A two-prong VIC-20 (ASSY No. 324003)
3. A VIC-20CR (ASSY No. ASSY250403)
4. C64 ASSY No. 250469

The VickyTwenty has the S-Video modification (sleepingelephant.com (http://sleepingelephant.com/denial/wiki/index.php?title=S-Video_output) or tech.guitarsite.de, (http://tech.guitarsite.de/vicky20_smod.html) respectively).

The retroTINK 2x (used with the HDMI capture device), the Framemeister (used with the TV) and a Samsung smart TV served as video equipment. A 1.5m RCA A/V cable connected the computer to the video equipment.

## Functional Test

The A/V adapter was connected to the computers and the video was displayed properly, the audio could be heard.

Figure 1: Boot screen of the VIC-20 CR (Hyper Expander RAM expansion installed)

The video quality was as good as it can get with the unmodified VIC-20. The video quality of ASSY No. 324003 is best, next is the Vicky Twenty.


VIC_AVada_Test.docx | | 01.11.2021 12:37
Drafted by Sven Petersen | Page 2 of 8 | Doc.-No.: 185-6-02-01

Figure 2: Photo of the BASIC start up screen of the VickyTwenty with the S-Video mod

Figure 3: Donkey Kong on the VickyTwenty/S-Video mod


VIC_AVada_Test.docx | | 01.11.2021 12:37
Drafted by Sven Petersen | Page 3 of 8 | Doc.-No.: 185-6-02-01

Figure 4: PENULTIMATE+ Cartridge on VickyTwenty / S-Video mod

Figure 5: PENULTIMATE+ Cartridge (composite video) on a VIC-20CR

The improvement due to the S-Video mod is obvious when comparing Figure 4 and Figure 4Figure 5.


VIC_AVada_Test.docx | | 01.11.2021 12:37
Drafted by Sven Petersen | Page 4 of 8 | Doc.-No.: 185-6-02-01

Figure 6: Composite output of the S-Video modded VickyTwenty (photo)

As expected, the composite output of the VickyTwenty with S-Video mod produces a black&white picture only, since the composite output is now luminance.

Figure 7: S-Video output of a VIC-20CR without the S-Video mod on a Framemeister

As expected, the video quality is low from the s-video jack on an unmodified VIC-20CR. Here, pin 4 and pin 5 of the A/V jack are both composite (instead of luma/chroma for S-Video).


VIC_AVada_Test.docx | | 01.11.2021 12:37
Drafted by Sven Petersen | Page 5 of 8 | Doc.-No.: 185-6-02-01

Figure 8: S-Video output of the unmodified VIC-20 (2 prong)

As expected, the output is degraded. The 2-prong VIC-20 has a different video circuitry as the VIC-20CR. Pin 4 and pin 5 are not tied together, but pin 4 is a composite signal (Pin 5) after an L/Clow pass filter. Thus, the different output “quality” of incorrectly connected VIC-20s.


VIC_AVada_Test.docx | | 01.11.2021 12:37
Drafted by Sven Petersen | Page 6 of 8 | Doc.-No.: 185-6-02-01

Figure 9: Photo of the C64 boot screen (composite Video)

Figure 10: C64 S-Video output

As expected, the S-Video output of the C64 does not work properly. The display is black and white, since Pin 5 (which is chrominance on a modified VIC-20) is audio in on the C64. Neither the C64 nor the Framemeister were harmed during this experiment.

## Mechanical Testing


VIC_AVada_Test.docx | | 01.11.2021 12:37
Drafted by Sven Petersen | Page 7 of 8 | Doc.-No.: 185-6-02-01

The VIC-20 A/V adapter did not block any port of the said computers.

Figure 11: Testing the A/V adapter with a two-prong VIC-20

Again, the connection is stable and no ports are blocked with the ASSY No. 324003 two-prong VIC-20.

Figure 12: Fitting of the A/V-Adapter with a VIC-20CR

VIC_AVada_Test.docx | | 01.11.2021 12:37
Drafted by Sven Petersen | Page 8 of 8 | Doc.-No.: 185-6-02-01

## Conclusion

The VIC-20 A/V-Adapter works well with different equipment. The video quality depends very much on the used video equipment. The video adapter will not improve the picture of the computers, since it is passive only, but since it allows to use good, off the shelve cables, it is superior to most hand-made custom cables.

Connecting S-Video to not modified VIC-20s does not harm the video equipment or the computer, but the quality is degraded. The same applies to the C64, which has its dedicated S-Video pins, that are not connected to the S-Video jack of the VIC-20 A/V-Adapter. The composite out of the C64 is displayed properly through the VIC-20 A/V-Adapter.

The VIC-20 A/V-Adaptor Rev. 1 is fully functional.

Pos. Qty Value Footprint Ref.-No. Comment

1 1 185-2-01-01 2 Layer PCB Rev. 1 2 layer, Cu 35µ, HASL, 39.0mm x 29.0mm, 1.6mm FR4

2 1 BTOR1 RED BTOR1 J4 Lumberg, RCA jack, vertical, red. E.G. Reichelt LUM BTOR1

RT, Farnell: 1368644, Newark: 53M6863, TME.eu:

BTOR1R

3 1 BTOR1 WHITE BTOR1 J3 Lumberg, RCA jack, vertical, white. E.G. Reichelt LUM
BTOR1 WS, Farnell: 1368645, Newark: 53M6864,

TME.eu: BTOR1W

4 1 BTOR1 YELLOW BTOR1 J2 Lumberg, RCA jack, vertical, yellow. E.G. Reichelt LUM
BTOR1 GE, Farnell: 1368642, Newark: 53M6865,

TME.eu: BTOR1Y

5 1 SV50 SV50_INNER J1 Inner part of Lumberg SV 50 (SV 50-8), e.G. Reichelt: LUM
SV 50, Newark: 82AH3339 , Farnell: 3549652, TME.eu:

SV50, alliedelec.com: 70151556

6 1 solder bridge JP1 structure on PCB, close for proper operation

7 1 RTC9028 MINIDIN4_V J5 Mini-DIN, 4p, vertical. Not required for 5-pin and VIC-20.

E.g. AliExpress:

### 8 RTConnector: RTC9028

### 9 ebay.de

## VIC-20 A/V-Adaptor Rev. 1

## Bill of Material Rev. 1.0

VIC20_AV_Adapt_BOM_v1_0.xlsx

Drafted by Sven Petersen Page 1 of 1

01.11.2021 13:10
Doc.No.: 185-5-01-01.0

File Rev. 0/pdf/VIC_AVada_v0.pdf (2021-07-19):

# Project Documentation

## Commodore VIC-20 A/V-Adapter

## Project number: 185

## Revision: 0

## Date: 18.07.2021



VIC_AVada_ModD.docx | | 19.07.2021 12:15
Drafted by Sven Petersen | Page 1 of 3 | Doc.-No.: 185-6-01-00

### Commodore VIC-20 A/V-Adapter Rev. 0

### Module Description

## Introduction

The VIC-20 A/V-Adapter serves as a breakout module for the 5-pin A/V jack, which allows using off the shelve cables of desired length and quality for connecting the VIC-20 to video/audio equipment.

Figure 1: Dimensions of the PCB

The two audio jacks (Audio L and Audio R) are connected to the same signal, the (mono) Audio Out of the VIC-20.

A 3D printable case can be found in the project folder as well as a label for this case.

Figure 2: 3D printed case and assembled PCB


VIC_AVada_ModD.docx | | 19.07.2021 12:15
Drafted by Sven Petersen | Page 2 of 3 | Doc.-No.: 185-6-01-00

## Connectors

### A/V-Plug – J1

The A/V-Plug for the VIC-20 is the inner part of a Lumberg SV 50 DIN-Plug (180°).

Pin Signal
1 n.c.
2 GND
3 Audio Out (mono)
4 Composite Video
5 n.c.

### RCA-Jacks – J2, J3, J4

Connector Signal
J2 | Composite Video
J3 | Audio Out L (mono!)
J4 | Audio Out R (mono!)

## The DIN-Plug

The DIN-Plug is an essential part of this development. It is the inner part of a Lumberg SV 50 connector, which is not cheap, but it is definitely worth the money, since the flange is taking the forces introduced by the weight of the adapter and the cables. This way, the set-up is not hanging from the contacts, which might even damage those. Do not use a cheap connector without a flange, here.

## Assembly

First, the DIN connector has to be soldered. The pins should be aligned flush to the top side of the PCB. This can be accomplished by putting the PCB top down on a heat resistant, flat surface. Then solder one pin from the top (the solder pads are shaped in a way, that allows doing so), check, if it is really flush and the connector is perpendicular to the board, then solder the remaining pins.

Figure 3: Aligning the DIN-Connector

VIC_AVada_ModD.docx | | 19.07.2021 12:15
Drafted by Sven Petersen | Page 3 of 3 | Doc.-No.: 185-6-01-00

Now, place and solder the RCA jacks. They should be well aligned, too. The ground pins might require more energy to be soldered, so the use of a thick solder tip is recommended and may be even a higher temperature (450°C). After soldering, the pins should be trimmed (shorter than 1.5mm), so they fit into the 3D-Printed case. If you do not use a case, cover the pins with something like duct tape or small drops of hot glue to prevent scratching the case of your VIC-20.

## Compatibility

The adapter also fits the C64 (in case S-Video is not required), especially the first C64 model with the 5-pin A/V-jack (this does not have the S-Video outputs). The same is for the C16. The A/V-Adapter does not work for the C128, since it blocks the serial bus. The adapter was successfully tested with an Atari 800XL.











VIC_AVada_Test.docx | | 19.07.2021 12:07
Drafted by Sven Petersen | Page 1 of 5 | Doc.-No.: 185-6-02-00

### Commodore VIC-20 A/V-Adapter Rev. 0

### Test

## Test Setup

The tests were executed with a VIC-20 A/V-Adapter Rev. 0. These computers were used for testing:

1. A VickyTwenty (clone of the VIC-20CR) in a plexilaser.de case
2. A two-prong VIC-20 (ASSY No. 324003)
3. A VIC-20CR (ASSY No. ASSY250403)
4. C64 ASSY No. 250469
5. Atari 800XL

None of the computers had a modified video circuitry.

The retroTINK 2x and a Samsung smart TV served as video equipment. A 1.5m RCA A/V cable connected the computer to the video equipment.

## Functional Test

The A/V adapter was connected to the computers and the video was displayed properly, the audio could be heard.

Figure 1: Boot screen of the VIC-20 CR (Hyper Expander RAM expansion installed)

The video quality was as good as it can get with the unmodified VIC-20. The video quality of ASSY No. 324003 is best, next is the Vicky Twenty. The horizontal dark strips are matter of taking a picture of a monitor (=not synchronized). They are not present in the perception of the user.


VIC_AVada_Test.docx | | 19.07.2021 12:07
Drafted by Sven Petersen | Page 2 of 5 | Doc.-No.: 185-6-02-00

Figure 2: C64 boot screen captured with a (cheap) USB2.0 video grabber

Figure 3: Display of the Atari 800XL

## Mechanical Testing


VIC_AVada_Test.docx | | 19.07.2021 12:07
Drafted by Sven Petersen | Page 3 of 5 | Doc.-No.: 185-6-02-00

The VIC-20 A/V adapter did not block any port of the said computers.

Figure 4: Testing the adapter with the VickyTwenty (plexilaser.de case)

The A/V-adapter can be inserted far enough in the plexilaser.de case, the connection is stable.

Figure 5: Testing the A/V adapter with a two-prong VIC-20

Again, the connection is stable and no ports are blocked with the ASSY No. 324003 two-prong VIC-20.


VIC_AVada_Test.docx | | 19.07.2021 12:07
Drafted by Sven Petersen | Page 4 of 5 | Doc.-No.: 185-6-02-00

Figure 6: Fitting of the A/V-Adapter with a VIC-20CR

Figure 7: Testing the VIC-20 A/V-Adapter with a C64G

The A/V-adapter is not blocking any port on a C64 (C64G with an ASSY No. 250469 short board).


VIC_AVada_Test.docx | | 19.07.2021 12:07
Drafted by Sven Petersen | Page 5 of 5 | Doc.-No.: 185-6-02-00

Figure 8: Testing the VIC-20 A/V-Adapter with an Atari 800XL

The A/V-adapter fits the Atari 800XL, not perfectly due to the step in the case above the ports, but it still provides a stable connection and it does not block the ports. Since no parallel port equipment was available, this was not tested.

## Conclusion

The VIC-20 A/V-Adapter works well with different equipment. The video quality depends very much on the used video equipment. The video adapter will not improve the picture of the computers, since it is passive only, but since it allows to use good, off the shelve cables, it is superior to most hand-made custom cables.

The VIC-20 A/V-Adaptor Rev. 0 is fully functional.

Pos. Qty Value Footprint Ref.-No. Comment

1 1 185-2-01-00 2 Layer PCB Rev. 0 2 layer, Cu 35µ, HASL, 38.0mm x 28.0mm, 1.6mm FR4

2 1 BTOR1 RED BTOR1 J4 Lumberg, RCA jack, vertical, red. E.G. Reichelt LUM BTOR1

RT, Farnell: 1368644, Newark: 53M6863, TME.eu:

BTOR1R

3 1 BTOR1 WHITE BTOR1 J3 Lumberg, RCA jack, vertical, white. E.G. Reichelt LUM
BTOR1 WS, Farnell: 1368645, Newark: 53M6864,

TME.eu: BTOR1W

4 1 BTOR1 YELLOW BTOR1 J2 Lumberg, RCA jack, vertical, yellow. E.G. Reichelt LUM
BTOR1 GE, Farnell: 1368642, Newark: 53M6865,

TME.eu: BTOR1Y

5 1 SV50 SV50_INNER J1 Inner part of Lumberg SV 50 (SV 50-8), e.G. Reichelt: LUM
SV 50, Newark: 82AH3339 , Farnell: 3549652, TME.eu:

SV50, alliedelec.com: 70151556

## VIC-20 A/V-Adaptor Rev. 0

## Bill of Material Rev. 0.0

VIC20_AV_Adapt_BOM_v0_0.xlsx

Drafted by Sven Petersen Page 1 of 1

19.07.2021 09:48
Doc.No.: 185-5-01-00.0

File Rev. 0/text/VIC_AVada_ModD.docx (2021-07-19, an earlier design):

Commodore VIC-20 A/V-Adapter Rev. 0

Module Description

# Introduction

The VIC-20 A/V-Adapter serves as a breakout module for the 5-pin A/V jack, which allows using off the shelve cables of desired length and quality for connecting the VIC-20 to video/audio equipment.


Figure 1: Dimensions of the PCB

The two audio jacks (Audio L and Audio R) are connected to the same signal, the (mono) Audio Out of the VIC-20.

A 3D printable case can be found in the project folder as well as a label for this case.


Figure 2: 3D printed case and assembled PCB

# Connectors

## A/V-Plug – J1

The A/V-Plug for the VIC-20 is the inner part of a Lumberg SV 50 DIN-Plug (180°).

Pin | Signal
1 | n.c.
2 | GND
3 | Audio Out (mono)
4 | Composite Video
5 | n.c.

## RCA-Jacks – J2, J3, J4

Connector | Signal
J2 | Composite Video
J3 | Audio Out L (mono!)
J4 | Audio Out R (mono!)

# The DIN-Plug

The DIN-Plug is an essential part of this development. It is the inner part of a Lumberg SV 50 connector, which is not cheap, but it is definitely worth the money, since the flange is taking the forces introduced by the weight of the adapter and the cables. This way, the set-up is not hanging from the contacts, which might even damage those. Do not use a cheap connector without a flange, here.

# Assembly

First, the DIN connector has to be soldered. The pins should be aligned flush to the top side of the PCB. This can be accomplished by putting the PCB top down on a heat resistant, flat surface. Then solder one pin from the top (the solder pads are shaped in a way, that allows doing so), check, if it is really flush and the connector is perpendicular to the board, then solder the remaining pins.


Figure 3: Aligning the DIN-Connector

Now, place and solder the RCA jacks. They should be well aligned, too. The ground pins might require more energy to be soldered, so the use of a thick solder tip is recommended and may be even a higher temperature (450°C). After soldering, the pins should be trimmed (shorter than 1.5mm), so they fit into the 3D-Printed case. If you do not use a case, cover the pins with something like duct tape or small drops of hot glue to prevent scratching the case of your VIC-20.

# Compatibility

The adapter also fits the C64 (in case S-Video is not required), especially the first C64 model with the 5-pin A/V-jack (this does not have the S-Video outputs). The same is for the C16. The A/V-Adapter does not work for the C128, since it blocks the serial bus. The adapter was successfully tested with an Atari 800XL.

VIC_AVada_ModD.docx 19.07.2021 12:15 Drafted by Sven Petersen Page 2 of 2 Doc.-No.: 185-6-01-00

VIC_AVada_ModD.docx 19.07.2021 12:15 Drafted by Sven Petersen Page 1 of 1 Doc.-No.: 000-6-00-00

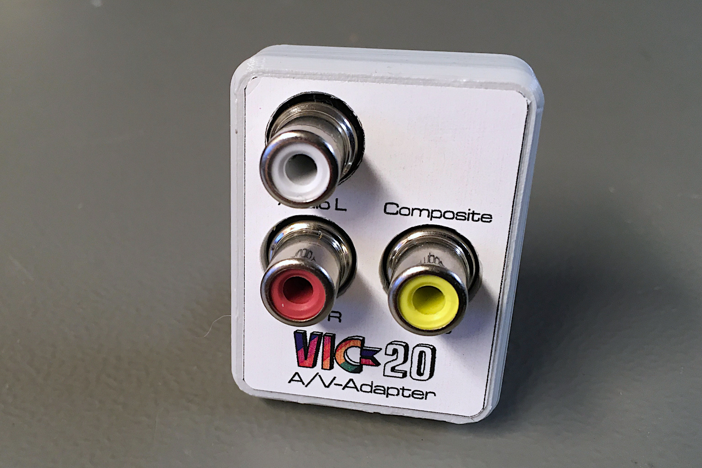
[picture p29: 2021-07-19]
Rev. 0/pictures/9023_-_in_case_front.JPG

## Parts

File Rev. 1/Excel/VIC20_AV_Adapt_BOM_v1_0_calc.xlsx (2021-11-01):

VIC-20 A/V-Adaptor Rev. 1
Bill of Material Rev. 1.0
Pos. | Qty | Value | €/each | Total | Comment
1 | 1 | 185-2-01-01 | 1.00 € | 1.00 € | 2 layer, Cu 35µ, HASL, 38.0mm x 28.0mm, 1.6mm FR4
2 | 1 | BTOR1 RED | 0.79 € | 0.79 € | Lumberg, RCA jack, vertical, red. E.G. Reichelt LUM BTOR1 RT, Farnell: 1368644, Newark: 53M6863, TME.eu: BTOR1R
3 | 1 | BTOR1 WHITE | 0.79 € | 0.79 € | Lumberg, RCA jack, vertical, white. E.G. Reichelt LUM BTOR1 WS, Farnell: 1368645, Newark: 53M6864, TME.eu: BTOR1W
4 | 1 | BTOR1 YELLOW | 0.79 € | 0.79 € | Lumberg, RCA jack, vertical, yellow. E.G. Reichelt LUM BTOR1 GE, Farnell: 1368642, Newark: 53M6865, TME.eu: BTOR1Y
5 | 1 | SV50 | 5.32 € | 5.32 € | Inner part of Lumberg SV 50 (SV 50-8), e.G. Reichelt: LUM SV 50, Newark: 82AH3339 , Farnell: 3549652, TME.eu: SV50, alliedelec.com: 70151556
6 | 1 | RTC9028 | 0.81 € | 0.81 € | Mini-DIN
7 |  | Total |  | 9.50 €

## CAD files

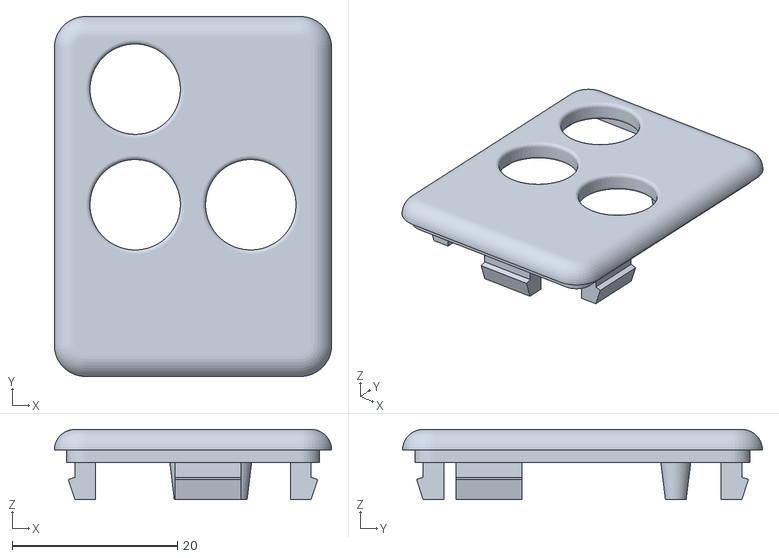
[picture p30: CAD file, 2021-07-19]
3Dprinted_case/Rev. 0/stl/VIC20_AV_top_shell.stl
33.6 x 43.6 x 8.50

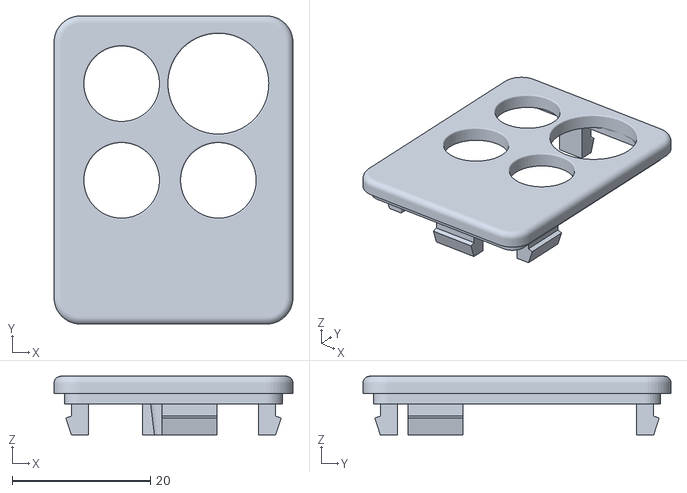
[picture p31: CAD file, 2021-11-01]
3Dprinted_case/Rev. 1/stl/VIC20_AV_top_v1.stl
34.6 x 44.6 x 8.50

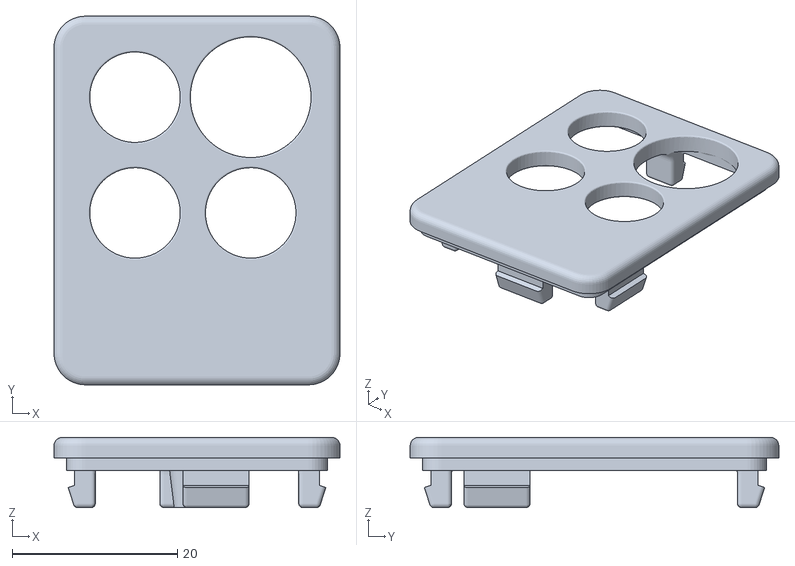
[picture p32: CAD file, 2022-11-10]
3Dprinted_case/Rev. 2/stl/VIC20AV_top_v2.stl
34.6 x 44.6 x 8.50

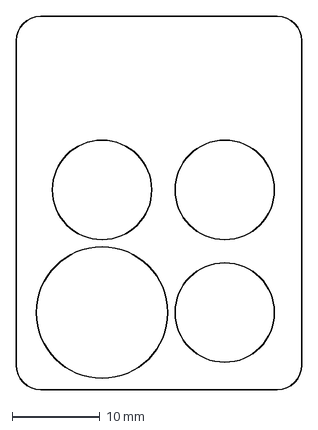
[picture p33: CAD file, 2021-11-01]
Rev. 1/dxf/label_outline.dxf
32.6 x 42.6 mm

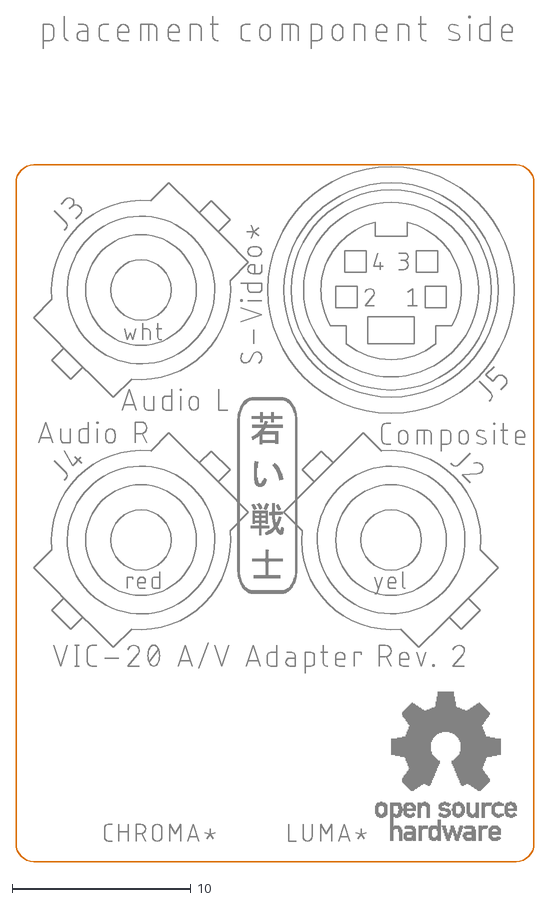
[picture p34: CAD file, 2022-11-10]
Rev. 2/dxf/VIC-20_AV-Adaptor_top.dxf
29.0 x 47.3

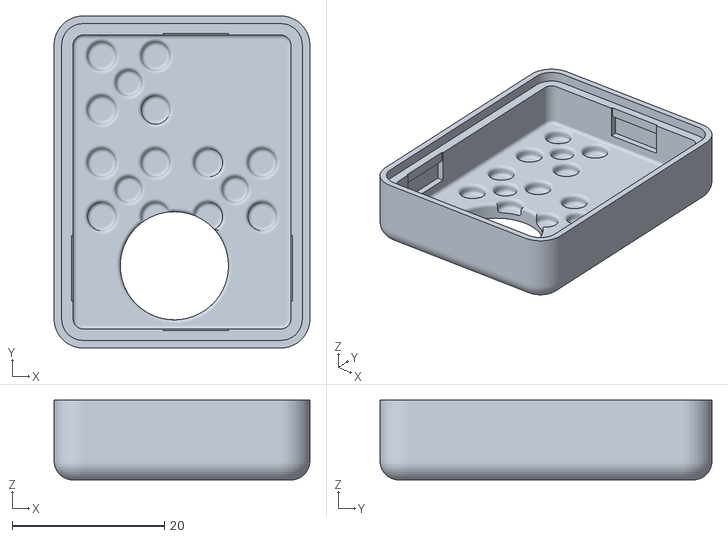
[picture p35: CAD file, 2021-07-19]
3Dprinted_case/Rev. 0/stl/VIC20_AV_bottom_shell.stl
33.6 x 43.6 x 10.5

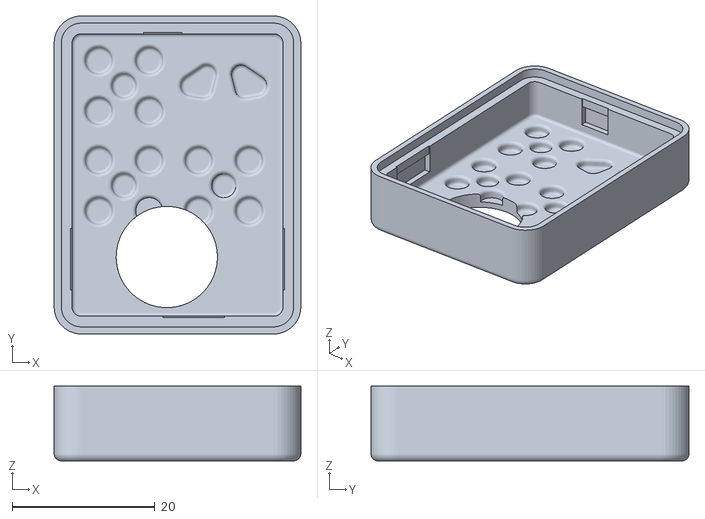
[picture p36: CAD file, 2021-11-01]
3Dprinted_case/Rev. 1/stl/VIC20_AV_bottom_v1.stl
34.6 x 44.6 x 10.5

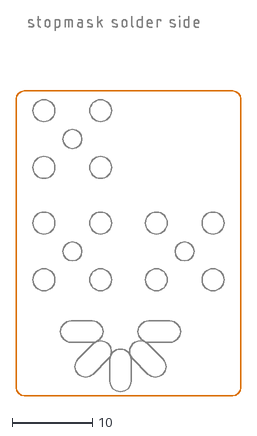
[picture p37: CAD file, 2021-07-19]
Rev. 0/dxf/VIC-20_AV-Adaptor_bstop.dxf
28.0 x 47.3

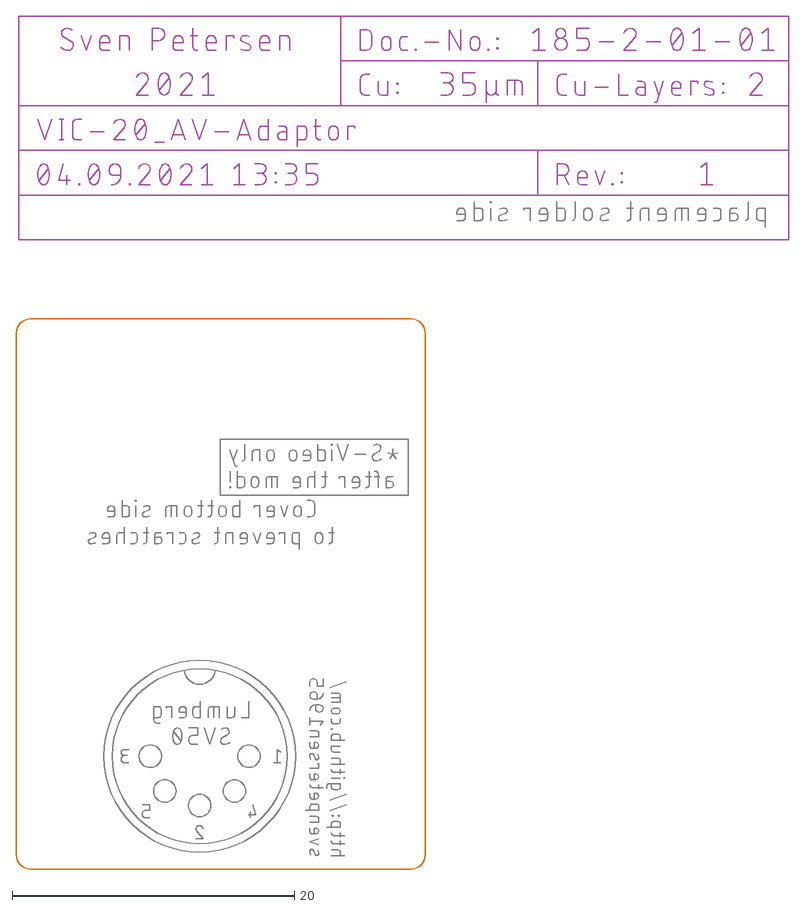
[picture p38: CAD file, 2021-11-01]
Rev. 1/dxf/VIC-20_AV-Adaptor_BOT.dxf
54.8 x 60.5

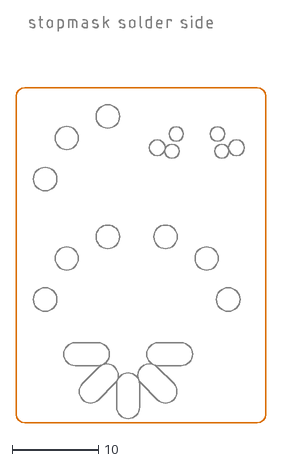
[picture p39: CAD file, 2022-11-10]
Rev. 2/dxf/VIC-20_AV-Adaptor_SolderPads.dxf
29.0 x 47.3

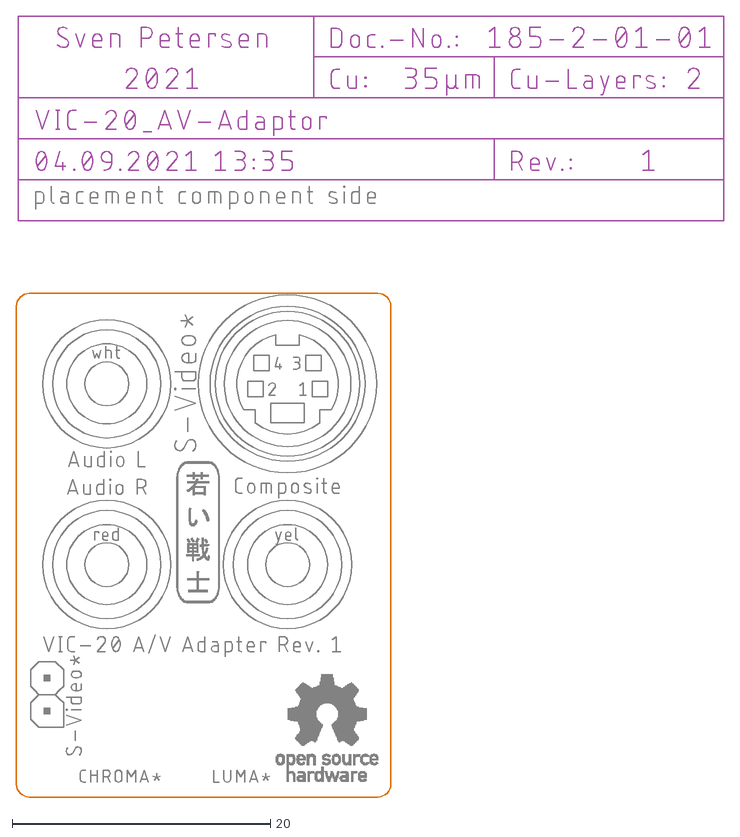
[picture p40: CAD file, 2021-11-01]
Rev. 1/dxf/VIC-20_AV-Adaptor_TOP.dxf
54.8 x 60.5

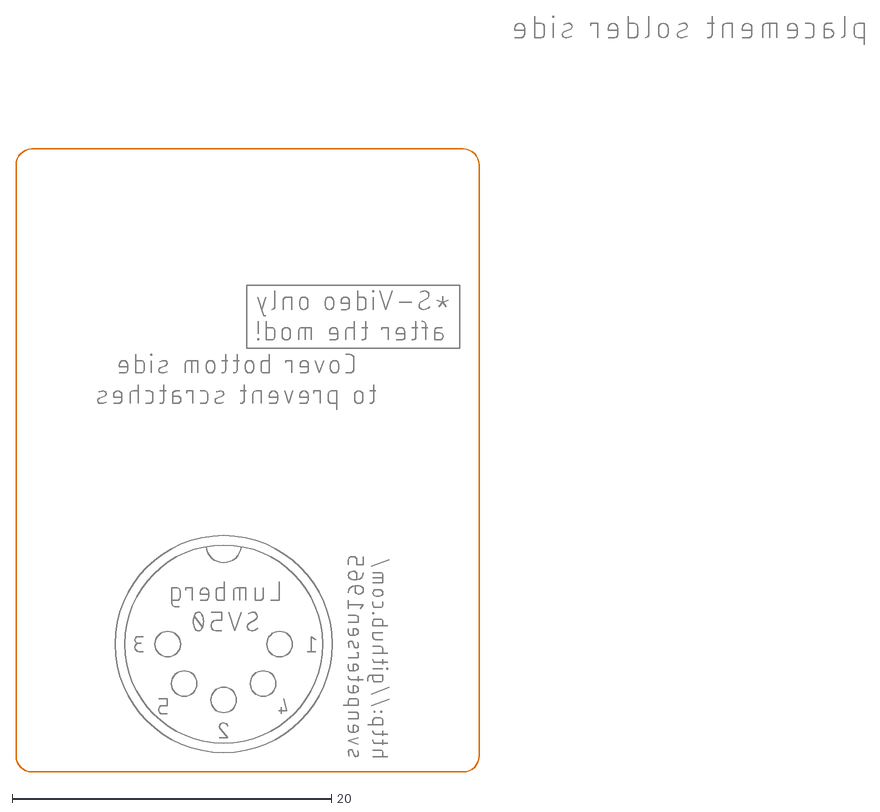
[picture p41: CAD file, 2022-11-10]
Rev. 2/dxf/VIC-20_AV-Adaptor_bot.dxf
53.1 x 47.3

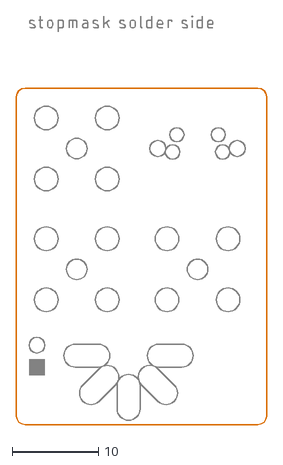
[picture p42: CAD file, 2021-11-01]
Rev. 1/dxf/VIC-20_AV-Adaptor_bottom_stop.dxf
29.0 x 47.3

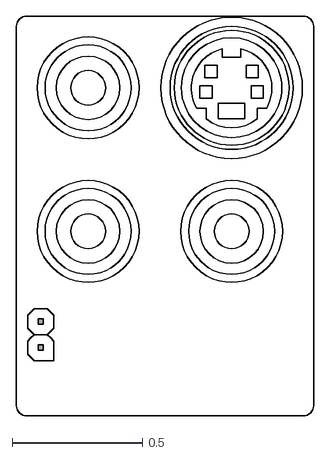
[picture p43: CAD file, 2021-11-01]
Rev. 1/dxf/VIC-20_AV-Adaptor_TOP1.DXF
1.14 x 1.54

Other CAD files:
3Dprinted_case/Rev. 2/stl/VIC20AV_bottom_v2.stl
Rev. 0/dxf/VIC-20_AV-Adaptor_bot.dxf
Rev. 0/dxf/VIC-20_AV-Adaptor_top.dxf
3Dprinted_case/Rev. 0/Fusion360/AV Adapter case v11.f3d
3Dprinted_case/Rev. 2/Fusion360/VIC-20_AV_Adapter_case v2 v2.f3d

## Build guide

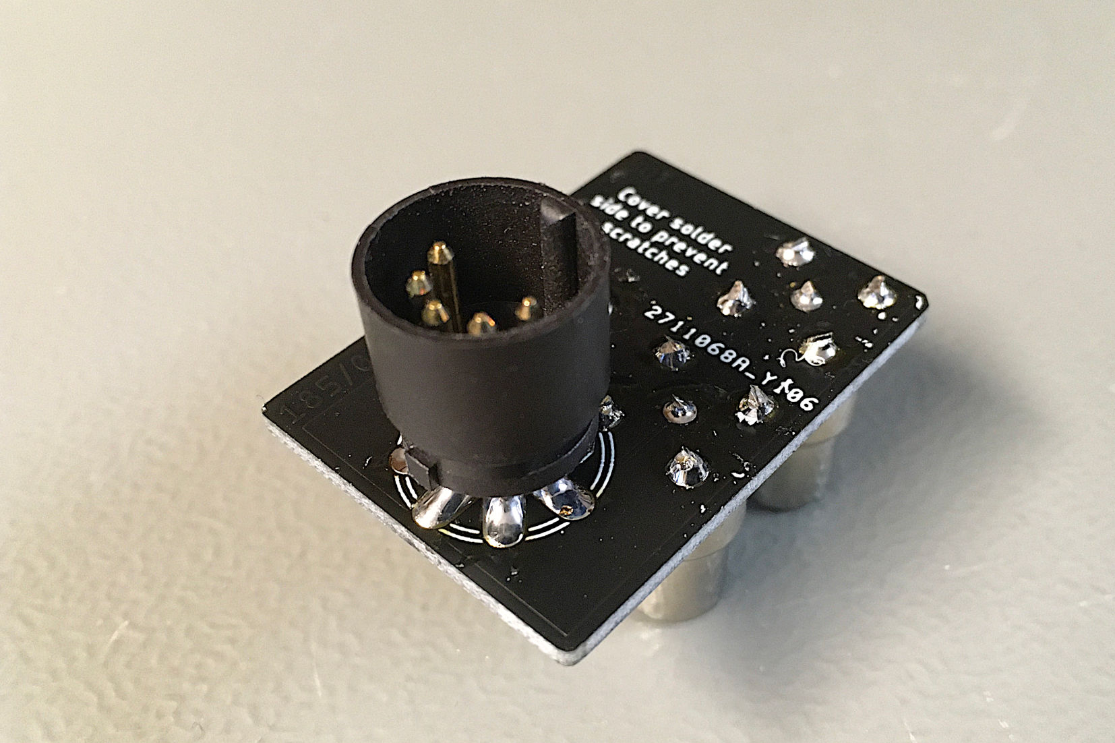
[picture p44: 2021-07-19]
Rev. 0/pictures/9024_-_solder_side.JPG

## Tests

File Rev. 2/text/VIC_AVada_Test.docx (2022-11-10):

Commodore VIC-20 A/V-Adapter Rev. 2

Test

# Test Setup

The tests were executed with a VIC-20 A/V-Adapter Rev. 1 and Rev. 2. These computers were used for testing:

1. A VickyTwenty (clone of the VIC-20CR) in a plexilaser.de case
2. A two-prong VIC-20 (ASSY No. 324003)
3. A VIC-20CR (ASSY No. ASSY250403)
4. C64 ASSY No. 250469

The VickyTwenty has the S-Video modification (sleepingelephant.com (http://sleepingelephant.com/denial/wiki/index.php?title=S-Video_output) or tech.guitarsite.de (http://tech.guitarsite.de/vicky20_smod.html), respectively).

The retroTINK 2x (used with the HDMI capture device), the Framemeister (used with the TV) and a Samsung smart TV served as video equipment. A 1.5m RCA A/V cable connected the computer to the video equipment.

# Functional Test

The A/V adapter was connected to the computers and the video was displayed properly, the audio could be heard.

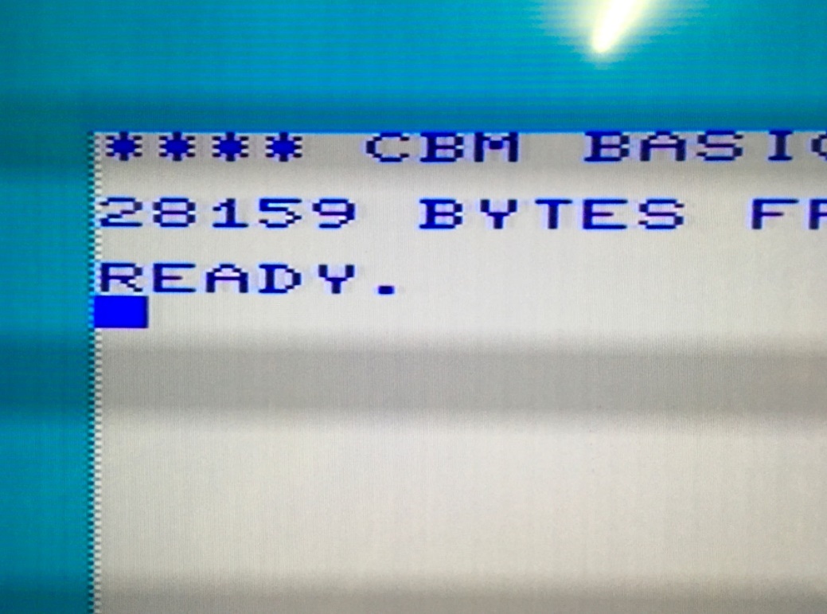
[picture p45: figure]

Figure 1: Boot screen of the VIC-20 CR (Hyper Expander RAM expansion installed)

The video quality was as good as it can get with the unmodified VIC-20. The video quality of ASSY No. 324003 is best, next is the Vicky Twenty.

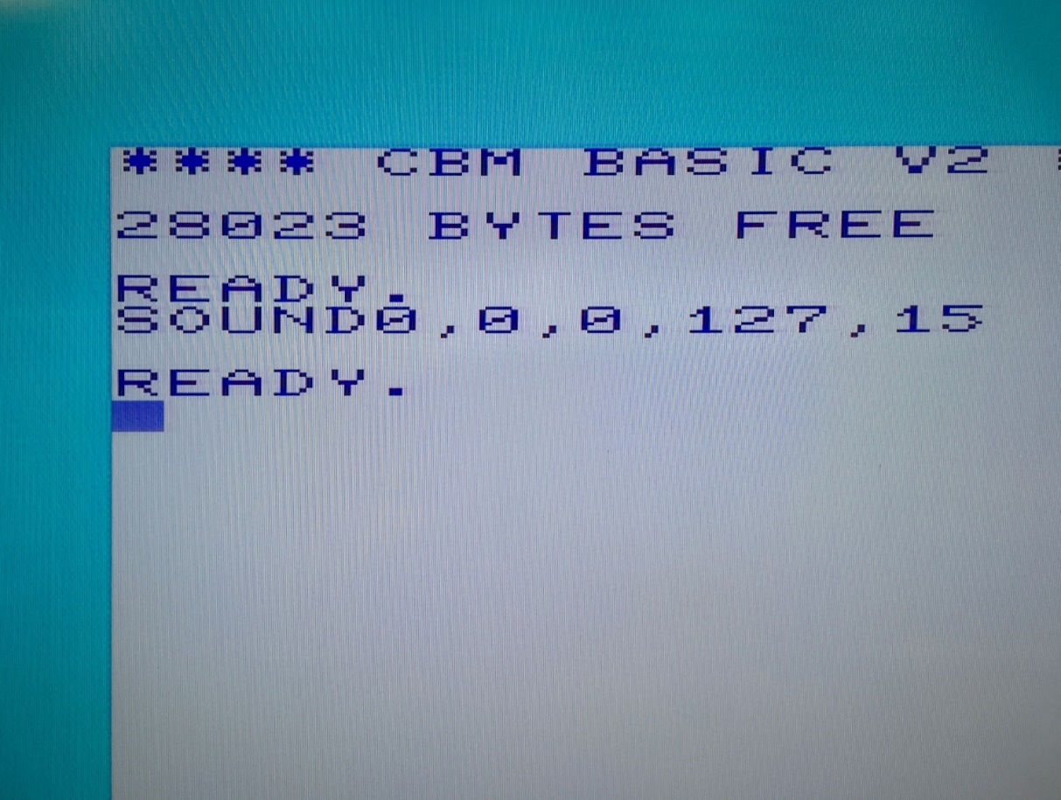
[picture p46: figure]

Figure 2: Photo of the BASIC start up screen of the VickyTwenty with the S-Video mod

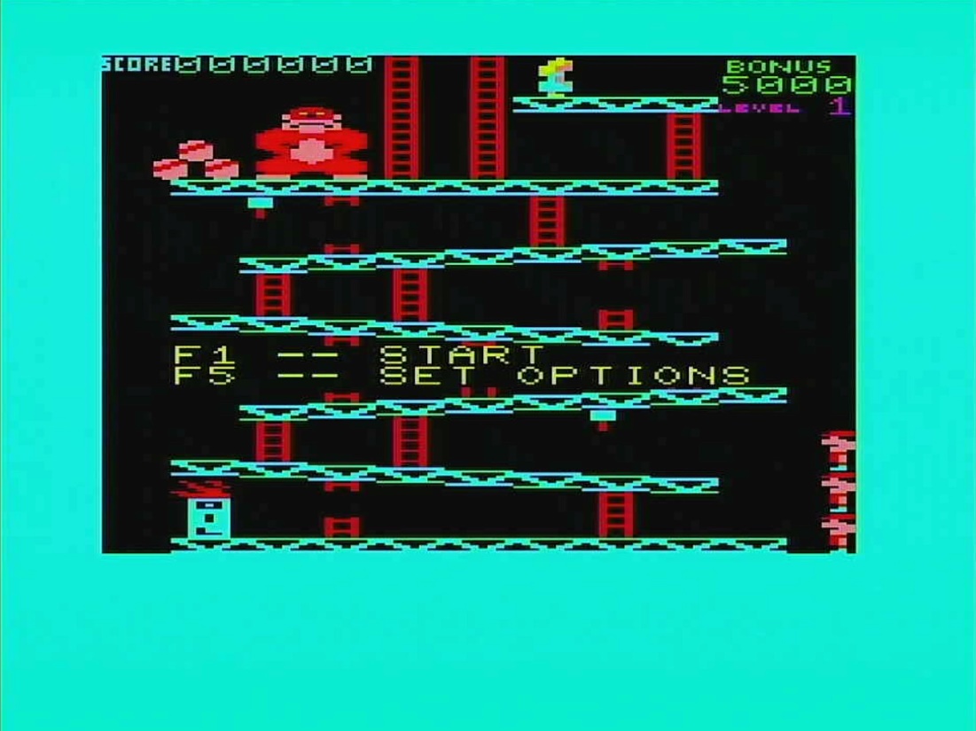
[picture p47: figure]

Figure 3: Donkey Kong on the VickyTwenty/S-Video mod

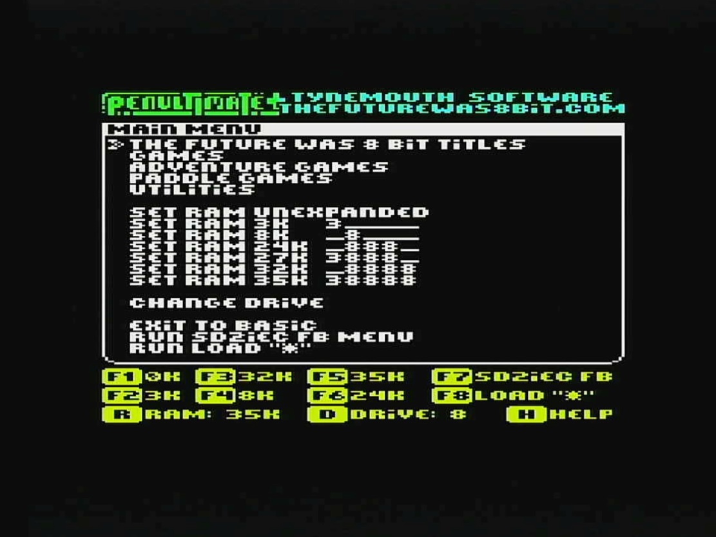
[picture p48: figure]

Figure 4: PENULTIMATE+ Cartridge on VickyTwenty / S-Video mod

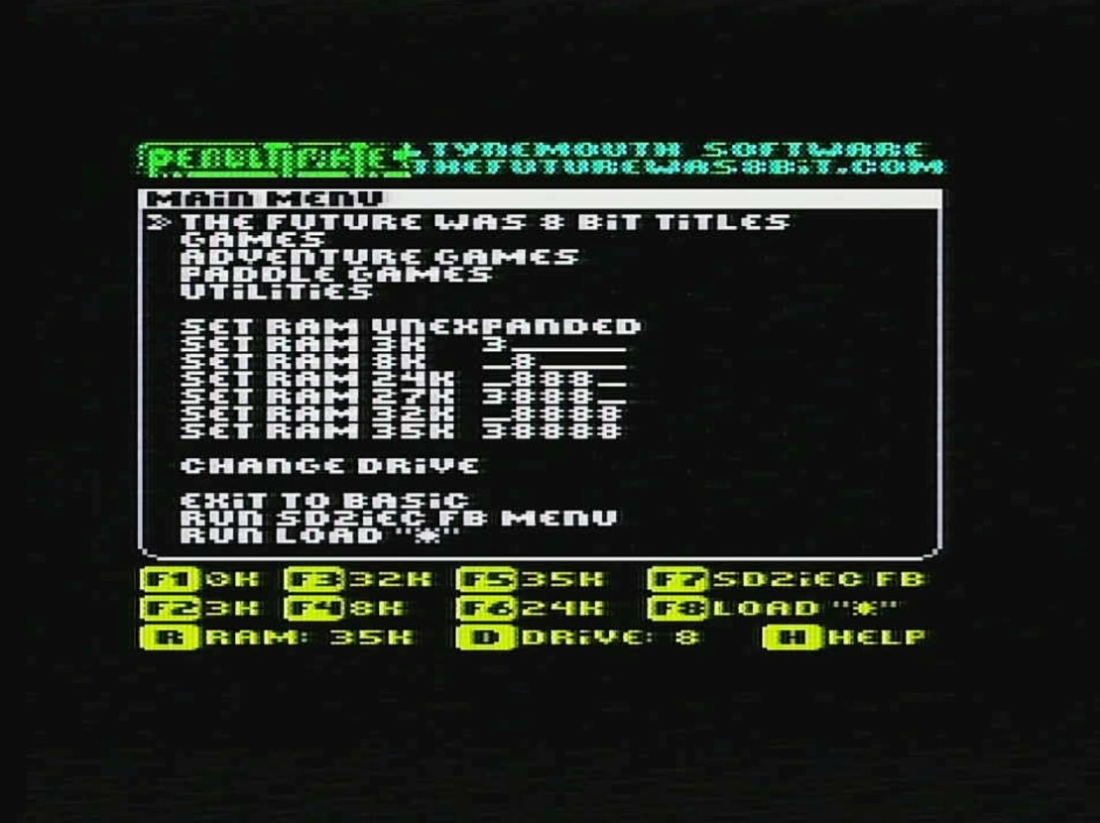
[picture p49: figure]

Figure 5: PENULTIMATE+ Cartridge (composite video) on a VIC-20CR

The improvement due to the S-Video mod is obvious when comparing Figure 4 and Figure 4Figure 5.

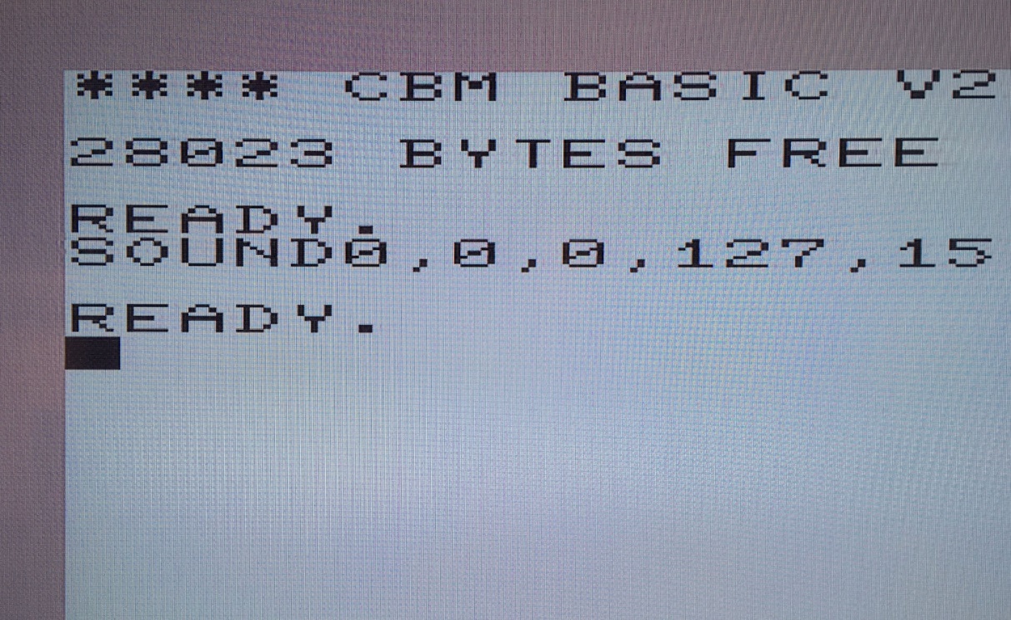
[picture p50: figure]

Figure 6: Composite output of the S-Video modded VickyTwenty (photo)

As expected, the composite output of the VickyTwenty with S-Video mod produces a black&white picture only, since the composite output is now luminance.

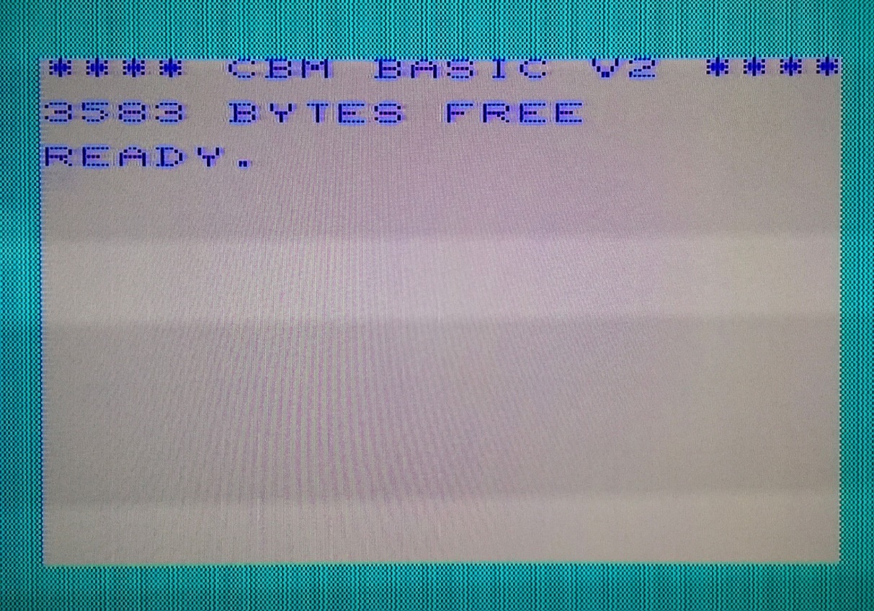
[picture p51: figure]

Figure 7: S-Video output of a VIC-20CR without the S-Video mod on a Framemeister

As expected, the video quality is low from the s-video jack on an unmodified VIC-20CR. Here, pin 4 and pin 5 of the A/V jack are both composite (instead of luma/chroma for S-Video).

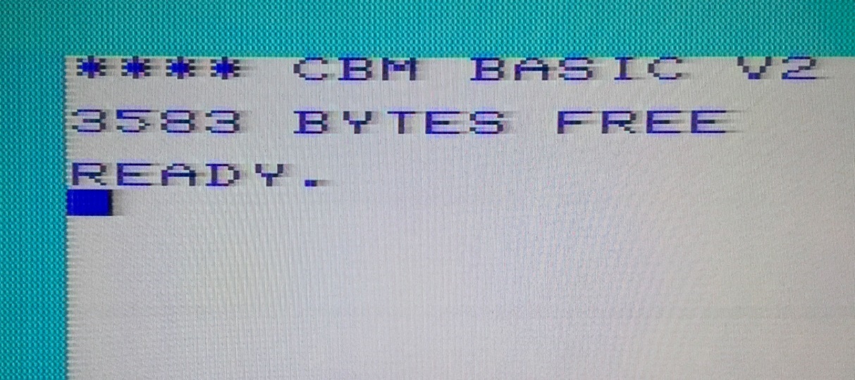
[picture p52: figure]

Figure 8: S-Video output of the unmodified VIC-20 (2 prong)

As expected, the output is degraded. The 2-prong VIC-20 has a different video circuitry as the VIC-20CR. Pin 4 and pin 5 are not tied together, but pin 4 is a composite signal (Pin 5) after an L/C-low pass filter. Thus, the different output “quality” of incorrectly connected VIC-20s.

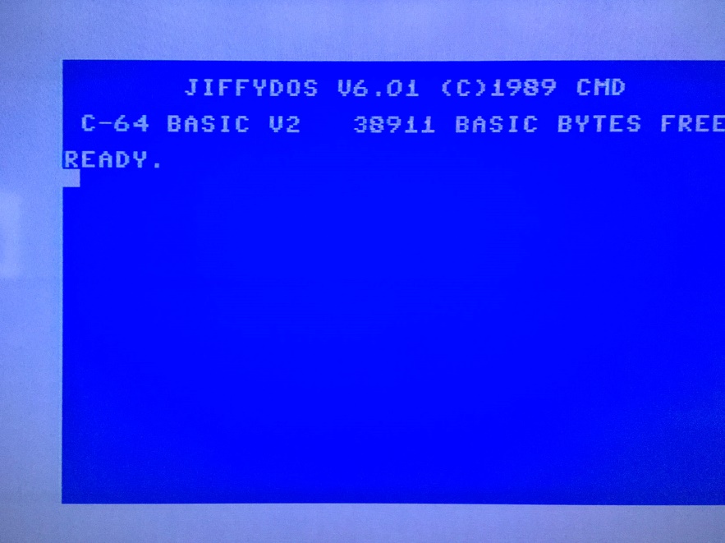
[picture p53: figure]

Figure 9: Photo of the C64 boot screen (composite Video)

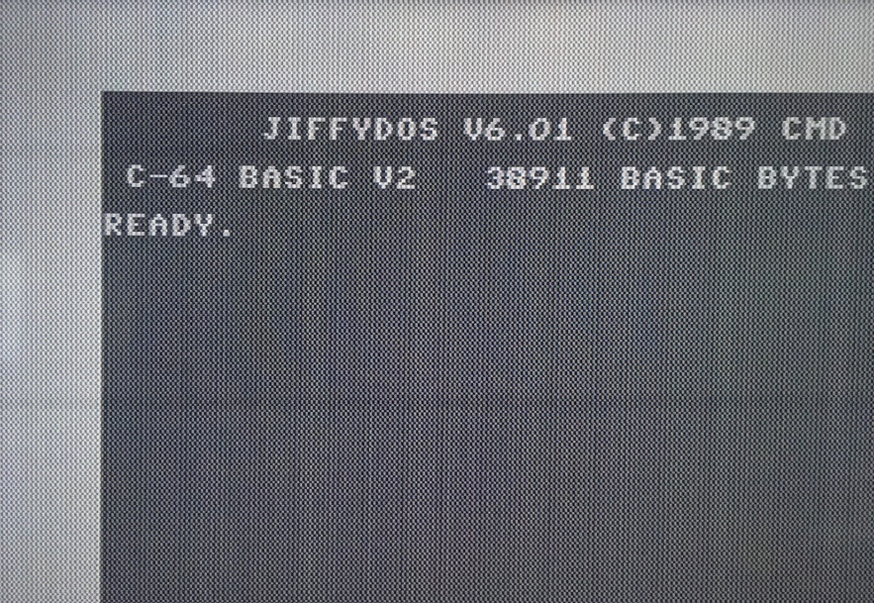
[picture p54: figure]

Figure 10: C64 S-Video output

As expected, the S-Video output of the C64 does not work properly. The display is black and white, since Pin 5 (which is chrominance on a modified VIC-20) is audio in on the C64. Neither the C64 nor the Framemeister were harmed during this experiment.

# Mechanical Testing

The VIC-20 A/V adapter did not block any port of the said computers.


Figure 11: Testing the A/V adapter with a two-prong VIC-20

Again, the connection is stable and no ports are blocked with the ASSY No. 324003 two-prong VIC-20.


Figure 12: Fitting of the A/V-Adapter with a VIC-20CR

# Conclusion

The VIC-20 A/V-Adapter works well with different equipment. The video quality depends very much on the used video equipment. The video adapter will not improve the picture of the computers, since it is passive only, but since it allows to use good, off the shelve cables, it is superior to most hand-made custom cables.

Connecting S-Video to not modified VIC-20s does not harm the video equipment or the computer, but the quality is degraded. The same applies to the C64, which has its dedicated S-Video pins, that are not connected to the S-Video jack of the VIC-20 A/V-Adapter. The composite out of the C64 is displayed properly through the VIC-20 A/V-Adapter.

The VIC-20 A/V-Adaptor Rev. 2 is fully functional.

VIC_AVada_Test.docx 10.11.2022 16:18 Drafted by Sven Petersen Page 2 of 2 Doc.-No.: 185-6-02-02

VIC_AVada_Test.docx 10.11.2022 16:18 Drafted by Sven Petersen Page 1 of 1 Doc.-No.: 000-6-00-00

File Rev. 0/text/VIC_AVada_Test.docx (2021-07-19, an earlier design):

Commodore VIC-20 A/V-Adapter Rev. 0

Test

# Test Setup

The tests were executed with a VIC-20 A/V-Adapter Rev. 0. These computers were used for testing:

1. A VickyTwenty (clone of the VIC-20CR) in a plexilaser.de case
2. A two-prong VIC-20 (ASSY No. 324003)
3. A VIC-20CR (ASSY No. ASSY250403)
4. C64 ASSY No. 250469
5. Atari 800XL

None of the computers had a modified video circuitry.

The retroTINK 2x and a Samsung smart TV served as video equipment. A 1.5m RCA A/V cable connected the computer to the video equipment.

# Functional Test

The A/V adapter was connected to the computers and the video was displayed properly, the audio could be heard.


Figure 1: Boot screen of the VIC-20 CR (Hyper Expander RAM expansion installed)

The video quality was as good as it can get with the unmodified VIC-20. The video quality of ASSY No. 324003 is best, next is the Vicky Twenty. The horizontal dark strips are matter of taking a picture of a monitor (=not synchronized). They are not present in the perception of the user.


Figure 2: C64 boot screen captured with a (cheap) USB2.0 video grabber


Figure 3: Display of the Atari 800XL

# Mechanical Testing

The VIC-20 A/V adapter did not block any port of the said computers.


Figure 4: Testing the adapter with the VickyTwenty (plexilaser.de case)

The A/V-adapter can be inserted far enough in the plexilaser.de case, the connection is stable.


Figure 5: Testing the A/V adapter with a two-prong VIC-20

Again, the connection is stable and no ports are blocked with the ASSY No. 324003 two-prong VIC-20.


Figure 6: Fitting of the A/V-Adapter with a VIC-20CR


Figure 7: Testing the VIC-20 A/V-Adapter with a C64G

The A/V-adapter is not blocking any port on a C64 (C64G with an ASSY No. 250469 short board).


Figure 8: Testing the VIC-20 A/V-Adapter with an Atari 800XL

The A/V-adapter fits the Atari 800XL, not perfectly due to the step in the case above the ports, but it still provides a stable connection and it does not block the ports. Since no parallel port equipment was available, this was not tested.

# Conclusion

The VIC-20 A/V-Adapter works well with different equipment. The video quality depends very much on the used video equipment. The video adapter will not improve the picture of the computers, since it is passive only, but since it allows to use good, off the shelve cables, it is superior to most hand-made custom cables.

The VIC-20 A/V-Adaptor Rev. 0 is fully functional.

VIC_AVada_Test.docx 19.07.2021 12:07 Drafted by Sven Petersen Page 2 of 2 Doc.-No.: 185-6-02-00

VIC_AVada_Test.docx 19.07.2021 12:07 Drafted by Sven Petersen Page 1 of 1 Doc.-No.: 000-6-00-00

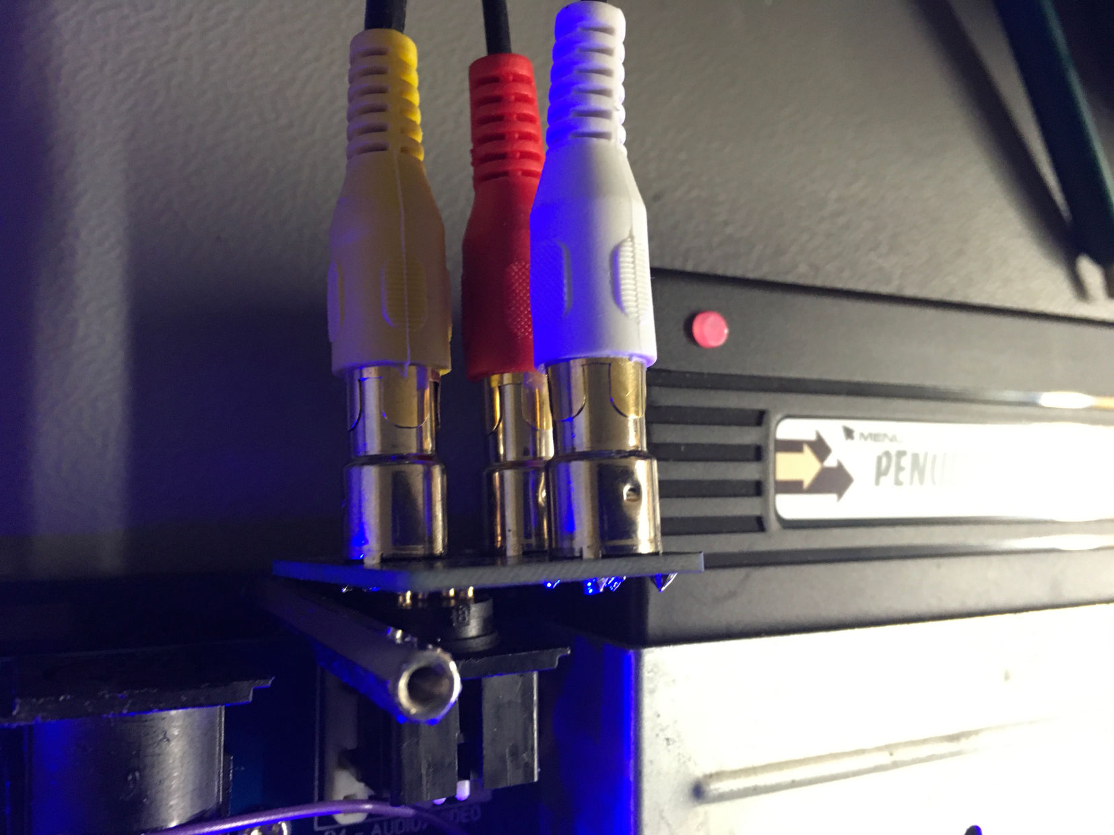
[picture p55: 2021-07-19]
Rev. 0/pictures/8902_-_Vicky_Twenty_Test.JPG

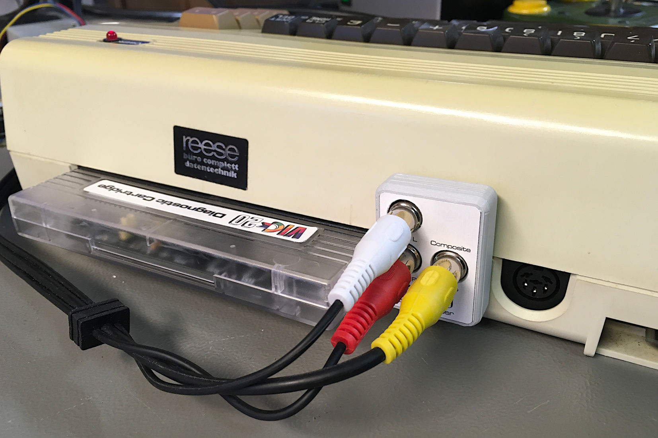
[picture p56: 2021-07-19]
Rev. 0/pictures/8997_-_Test_SN1960_TwoProng.JPG

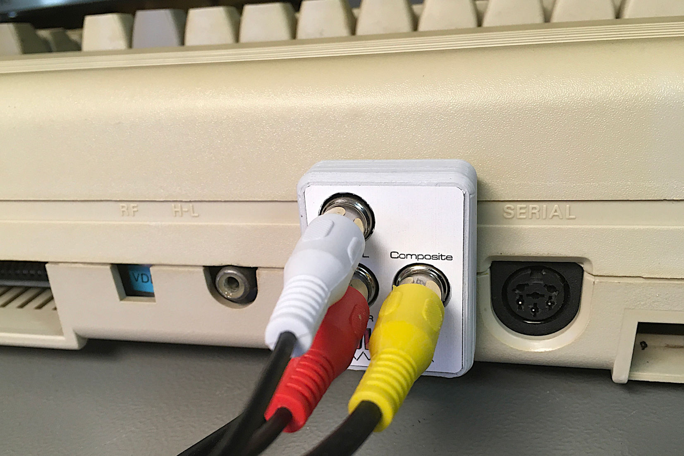
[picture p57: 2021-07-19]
Rev. 0/pictures/9042_-_testing_C64G.JPG

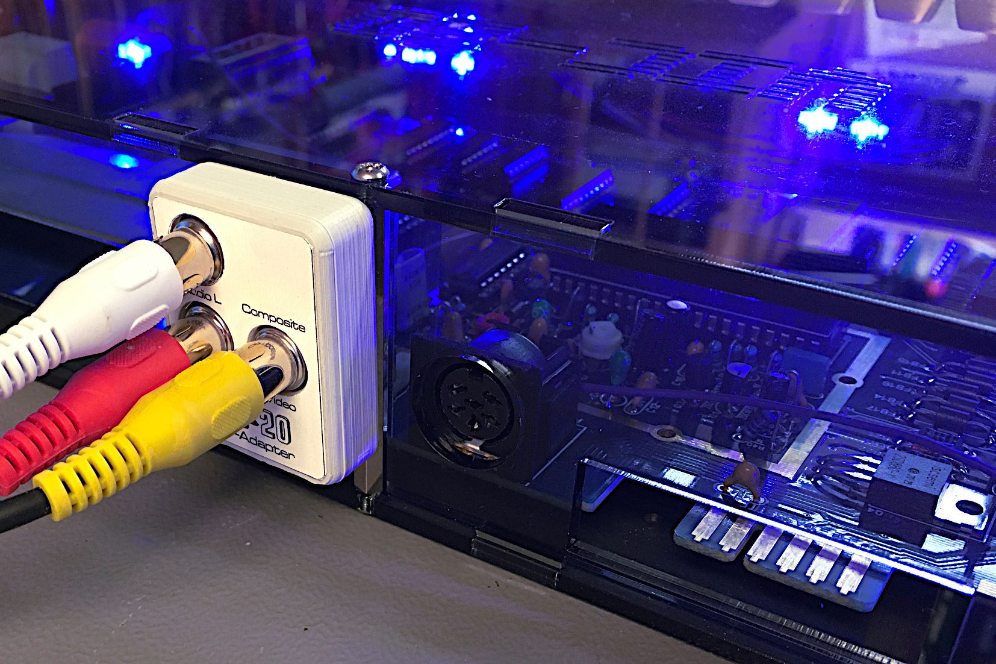
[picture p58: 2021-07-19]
Rev. 0/pictures/8996_-_Test_VickyTwenty.JPG

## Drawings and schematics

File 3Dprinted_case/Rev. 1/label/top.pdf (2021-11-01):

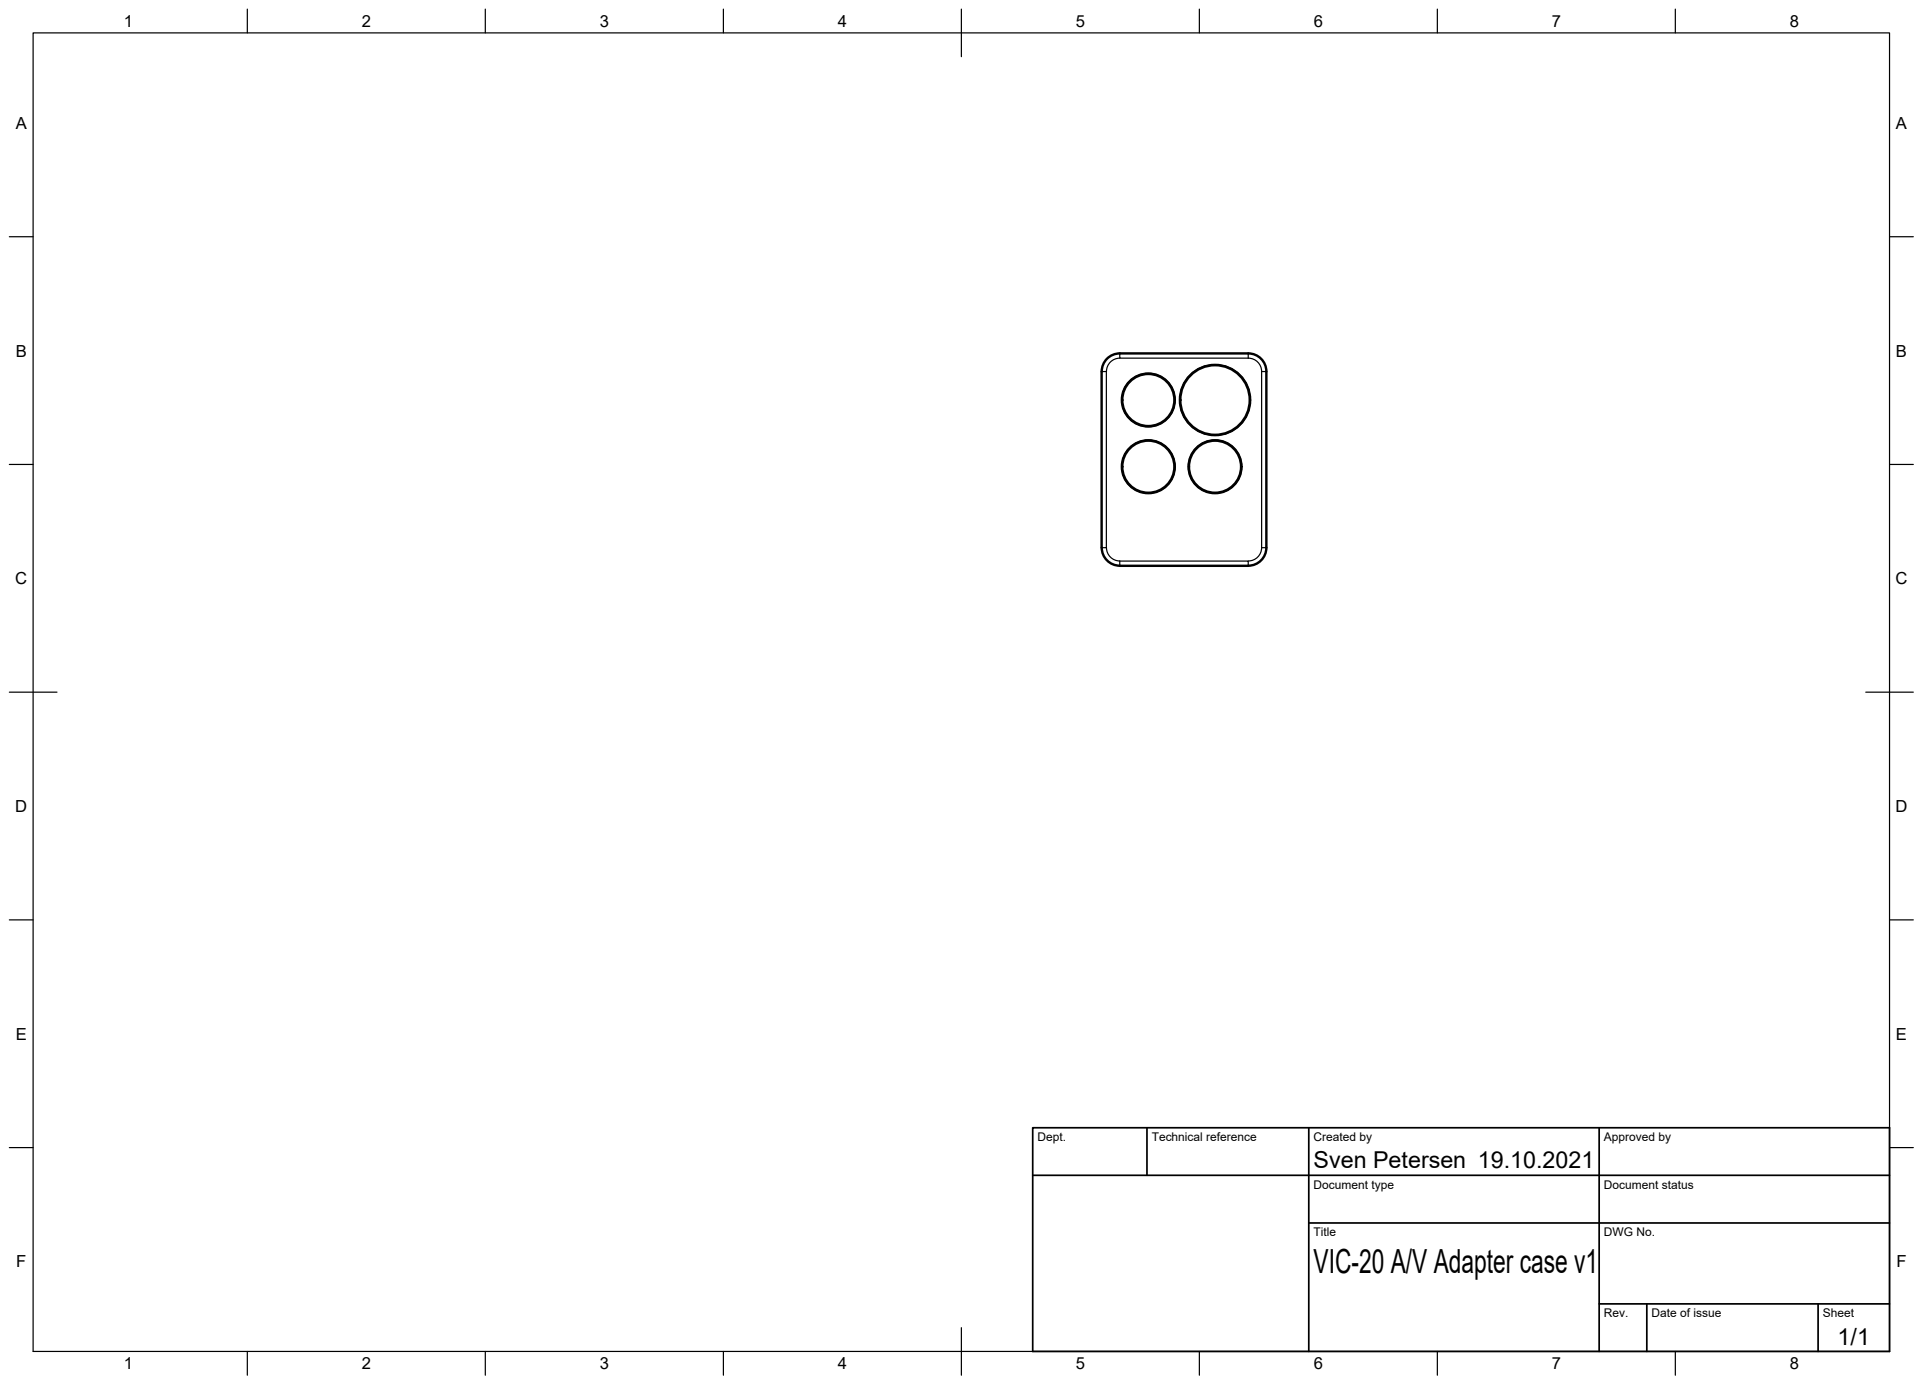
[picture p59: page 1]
Title; DWG No.; Rev.; Date of issue; Sheet

Dept. | Technical reference | Created by Sven Petersen 19.10.2021 | Approved by

Document type | Document status

VIC-20 A/V Adapter case v1

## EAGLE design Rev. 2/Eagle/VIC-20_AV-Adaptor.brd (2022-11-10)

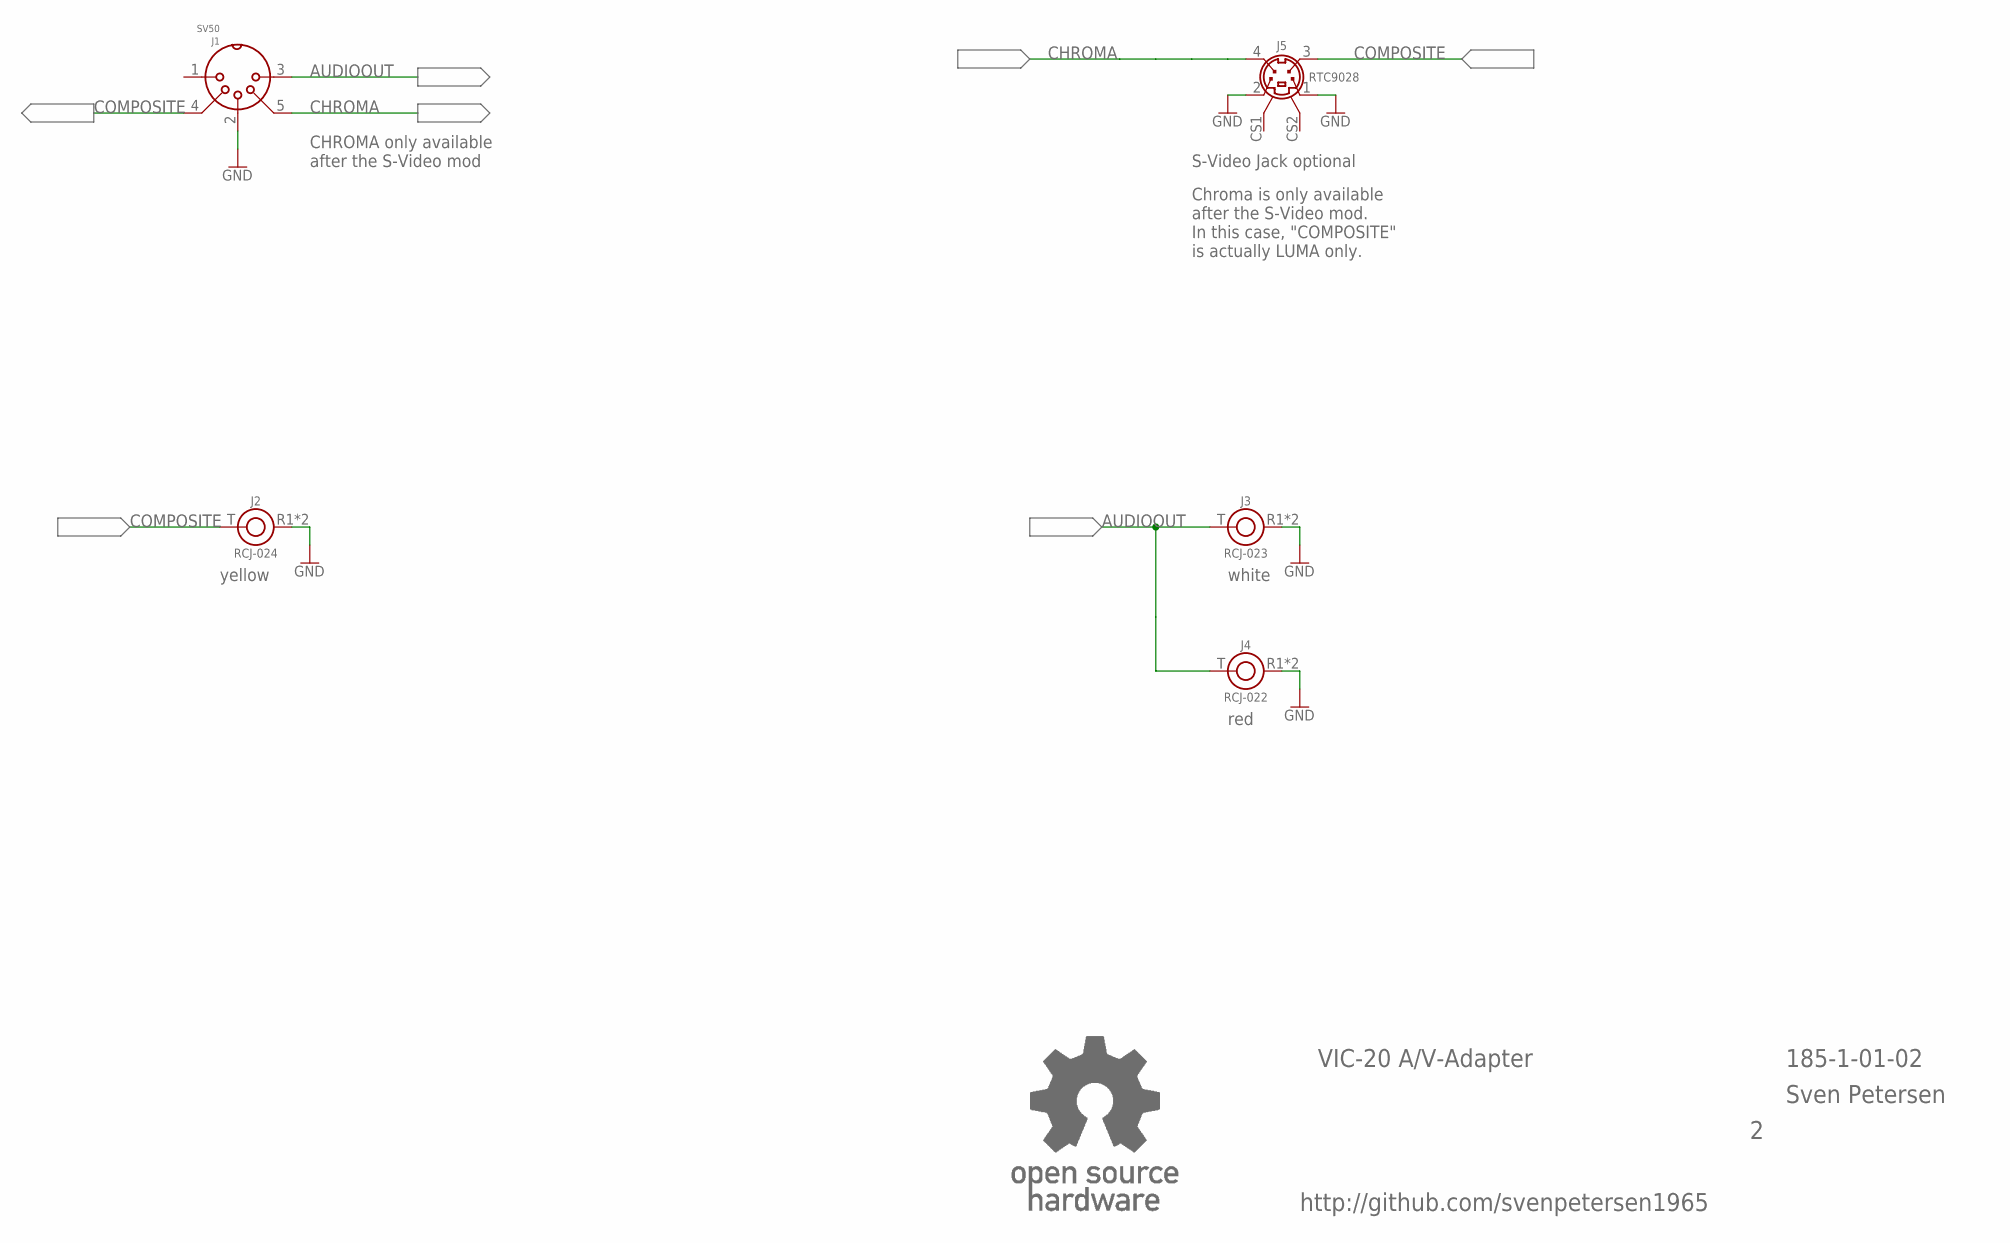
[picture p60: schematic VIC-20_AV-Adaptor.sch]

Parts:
J1: SV50; SV50_INNER
J2: RCJ-024; RCJ-02X
J3: RCJ-023; RCJ-02X
J4: RCJ-022; RCJ-02X
J5: RTC9028; MINIDIN4_V
U$25: OPEN_SOURCE_HW; OPENHW

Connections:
AUDIOOUT: J1.3, J3.T, J4.T
CHROMA: J1.5, J5.4
COMPOSITE: J1.4, J2.T, J5.3
GND: J1.2, J2.R1 (R), J2.R2 (R), J3.R1 (R), J3.R2 (R), J4.R1 (R), J4.R2 (R), J5.1, J5.2

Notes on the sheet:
VIC-20 A/V-Adapter
185-1-01-02
Sven Petersen
http://github.com/svenpetersen1965
CHROMA only available after the S-Video mod
S-Video Jack optional
Chroma is only available after the S-Video mod. In this case, "COMPOSITE" is actually LUMA only.
white
red
yellow

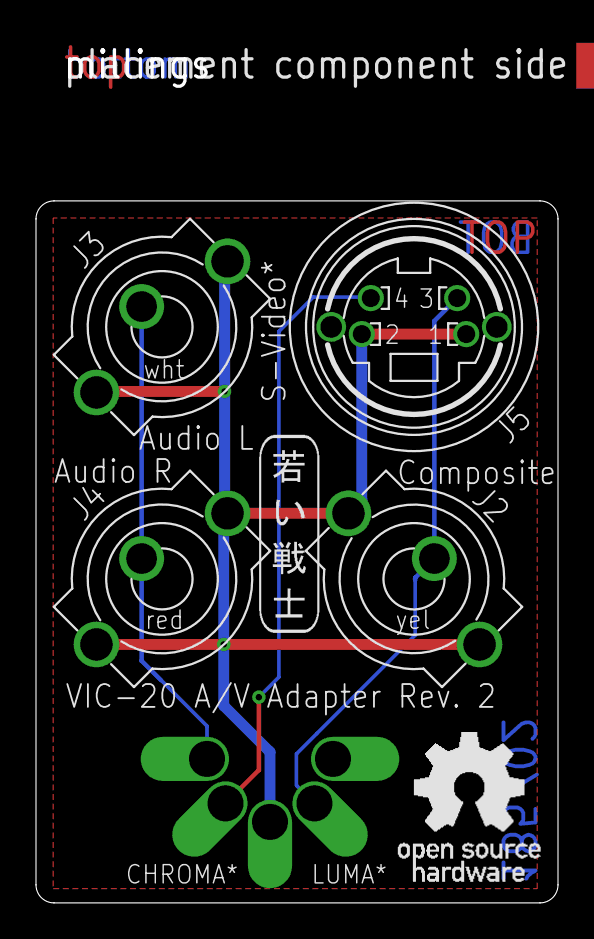
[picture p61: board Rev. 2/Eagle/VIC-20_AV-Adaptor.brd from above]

Board: 2 copper layers, 29.0 x 39.0 mm, 9 parts (1 on the bottom side), 4 nets.

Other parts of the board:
U$22: 2LAYER
U$23: SVEN_TAG
U$24: PCB-TITLE/

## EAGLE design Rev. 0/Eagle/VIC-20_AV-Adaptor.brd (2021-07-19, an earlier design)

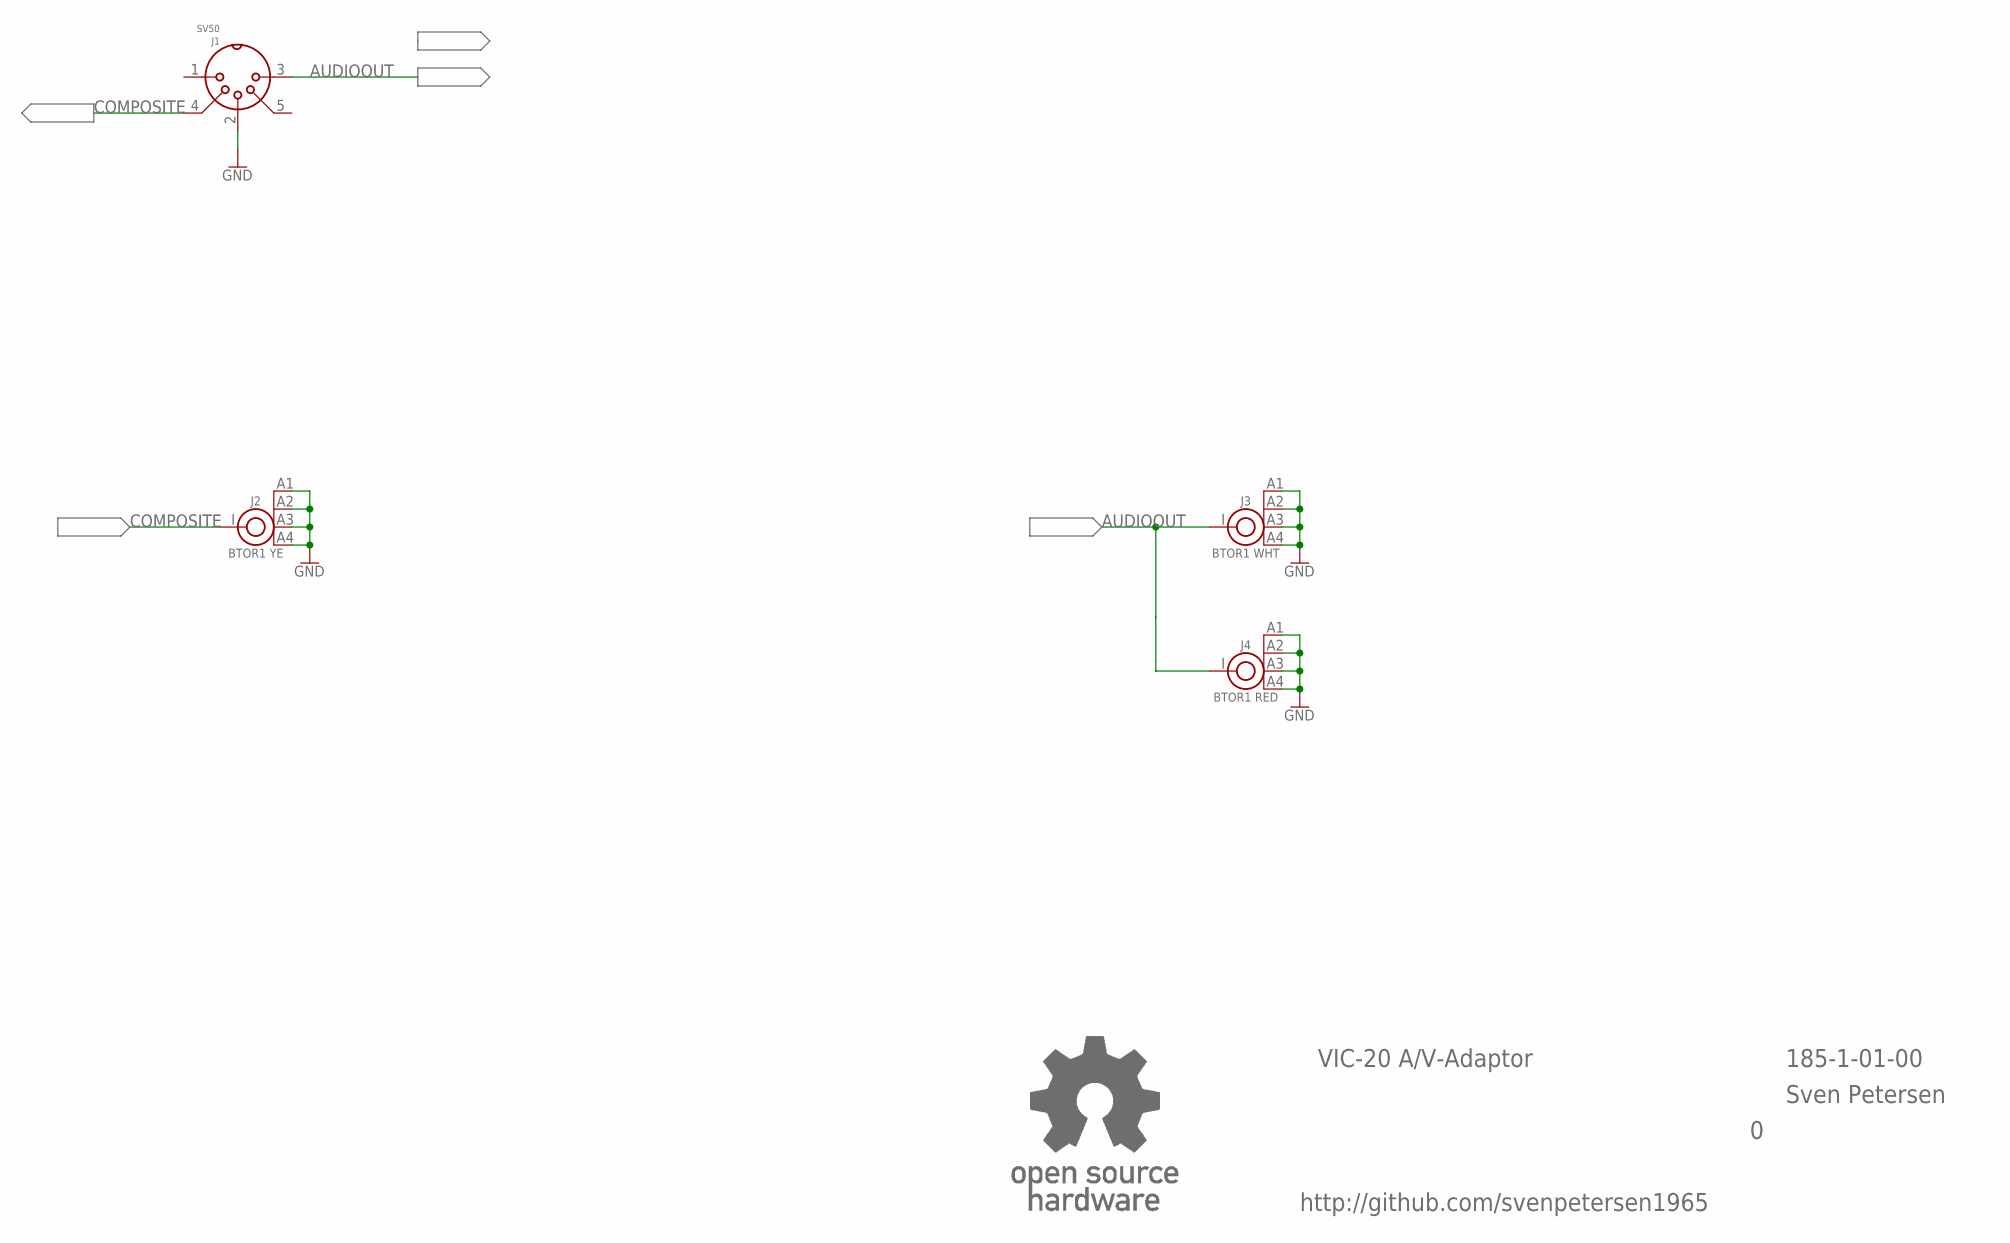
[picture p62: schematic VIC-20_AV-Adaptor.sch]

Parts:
J1: SV50; SV50_INNER
J2: BTOR1 YE; BTOR1
J3: BTOR1 WHT; BTOR1
J4: BTOR1 RED; BTOR1
U$25: OPEN_SOURCE_HW; OPENHW

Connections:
AUDIOOUT: J1.3, J3.I, J4.I
COMPOSITE: J1.4, J2.I
GND: J1.2, J2.A1, J2.A2, J2.A3, J2.A4, J3.A1, J3.A2, J3.A3, J3.A4, J4.A1, J4.A2, J4.A3, J4.A4

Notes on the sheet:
VIC-20 A/V-Adaptor
185-1-01-00
Sven Petersen
http://github.com/svenpetersen1965

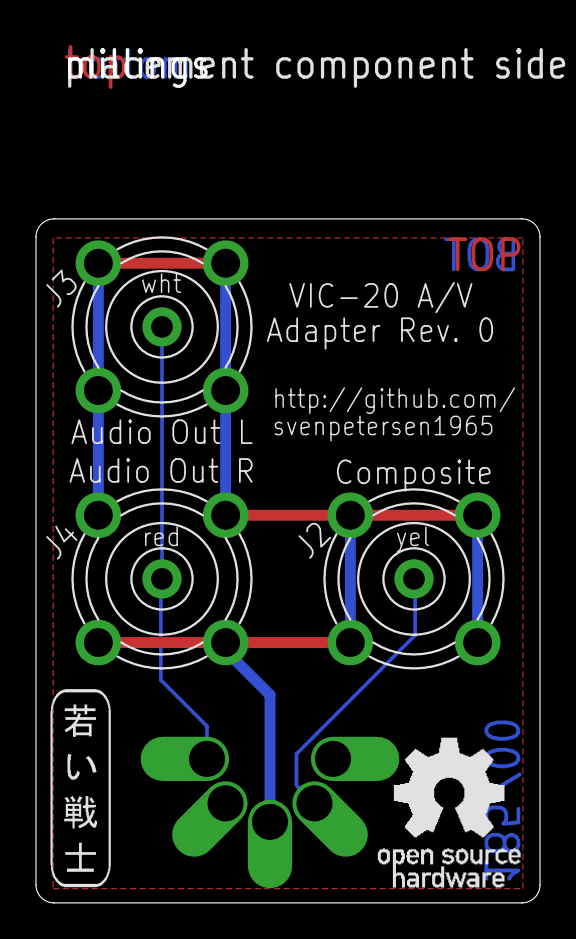
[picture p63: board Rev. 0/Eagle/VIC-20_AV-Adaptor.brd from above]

Board: 2 copper layers, 28.0 x 38.0 mm, 8 parts (1 on the bottom side), 3 nets.

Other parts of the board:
U$22: 2LAYER
U$23: SVEN_TAG
U$24: PCB-TITLE/

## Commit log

2021-07-19 Initial release
    [AV Adapter case v11.f3d, VIC-20_AV-Adaptor.brd, VIC-20_AV-Adaptor.sch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]
2021-08-03 Calculation added
    [VIC20_AV_Adapt_BOM_v0_0_calc.xlsx]
2021-11-01 Case Rev. 1 released
    [VIC20_AV_bottom_v1.stl, VIC20_AV_top_v1.stl]
2021-11-01 PCB Rev.1 released
    [VIC-20_AV-Adaptor.brd, VIC-20_AV-Adaptor.sch, VIC-20_AV-Adaptor_BOT.dxf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]
2021-11-01 Added calculation
    [VIC20_AV_Adapt_BOM_v1_0_calc.xlsx]
2022-02-26 Gerbers removed
2022-11-10 Rev. 2 released
    Revision 2 was required due to the obsolescence of the Lumber BTOR1 RCA jacks. They were replaced by CUI Inc. type jacks with a different footprint. This also requires a different case.
    [VIC-20_AV-Adaptor.brd, VIC-20_AV-Adaptor.sch, VIC-20_AV-Adaptor_SolderPads.dxf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]
2022-11-10 The case for the Rev. 2 PCB
    The PCB Rev. 2 requires a different bottom shell
    [VIC-20_AV_Adapter_case v2 v2.f3d, VIC20AV_bottom_v2.stl, VIC20AV_top_v2.stl]
